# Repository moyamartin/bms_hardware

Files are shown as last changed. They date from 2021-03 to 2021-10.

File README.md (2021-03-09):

# Battery Management System (BMS) - Hardware

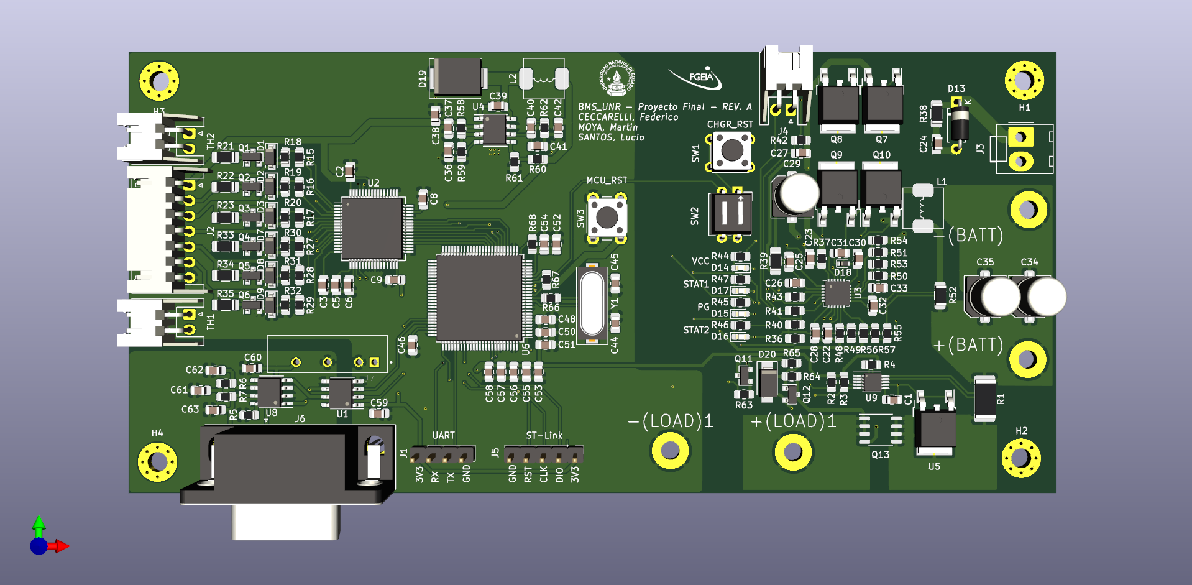
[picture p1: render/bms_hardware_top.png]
3d Render of the BMS


This is the hardware design section of the [BMS project](https://github.com/moyamartin/bms_unr). It was designed with [KiCAD](https://kicad.org/).

Here you will find the design, [gerber](./gerber/), [BOM](https://moyamartin.github.io/bms_hardware/) and [render](./render/) files of the PCB.

## Features

As the main goal of this project, this board is designed to support a li-ion
battery pack with a 6 series - 3 parallel architecture based on 18650PF cells
following the next goals:

* Protection
* Balancing
* Charging/Discharging
* Temperature measurement
* Battery SoC (State of Charge) estimation

## Design components/considerations

To meet the project's requirements we have chosen the following components with
their respective role:

* [BQ76PL536A](https://www.ti.com/product/BQ76PL536A): This is a 3 to 6 series
  lithium-ion battery monitor and secondary protection. It is used as a frontend
  analog device to measure each series cell voltage and it has dedicated outputs
  to balance passively through resistors the desired cell.

* [INA226](https://www.ti.com/lit/ds/symlink/ina226.pdf): Bi-Directional current
  and power monitor with I2C compatible interface, we are using this to measure
  the discharge current, fusioning this data with the voltage measurement of
  each cell we can infere the SoC of each cell.

* [BQ24618](https://www.ti.com/lit/ds/symlink/bq24618.pdf): 6 cells Li-Ion
  battery charger, designed to charge the battery pack at a 4A rate with led
  status indication.

* [STM32F407VGTx](https://www.st.com/en/microcontrollers-microprocessors/stm32f407vg.html): ARM Cortex-M microcontroller with DSP instructions and FPU unit, used to estimate the SoC and control all the peripherals and sensors through their respectives communication protocols applying all the mentioned features earlier. It is enabled to interact with other external devices (such as an on-board computer) through CAN and RS232.

* [SN65HVD233](https://www.ti.com/lit/ds/symlink/sn65hvd233.pdf): 3.3V CAN Bus
  transceiver to operate with the latter MCU compatible with ISO 11898 standard.
  This device is isolated from the rest of the components through the [ADuM1201AR](https://www.analog.com/media/en/technical-documentation/data-sheets/ADuM1200_1201.pdf).

* [IRF9310PbF](https://www.infineon.com/dgdl/irf9310pbf.pdf?fileId=5546d462533600a4015356110a7d1d95): Charge and Discarge switch for battery applications, this device is in charge of connection and disconnecting the load from the battery, basically, it's the main endpoint of proetection for the battery pack

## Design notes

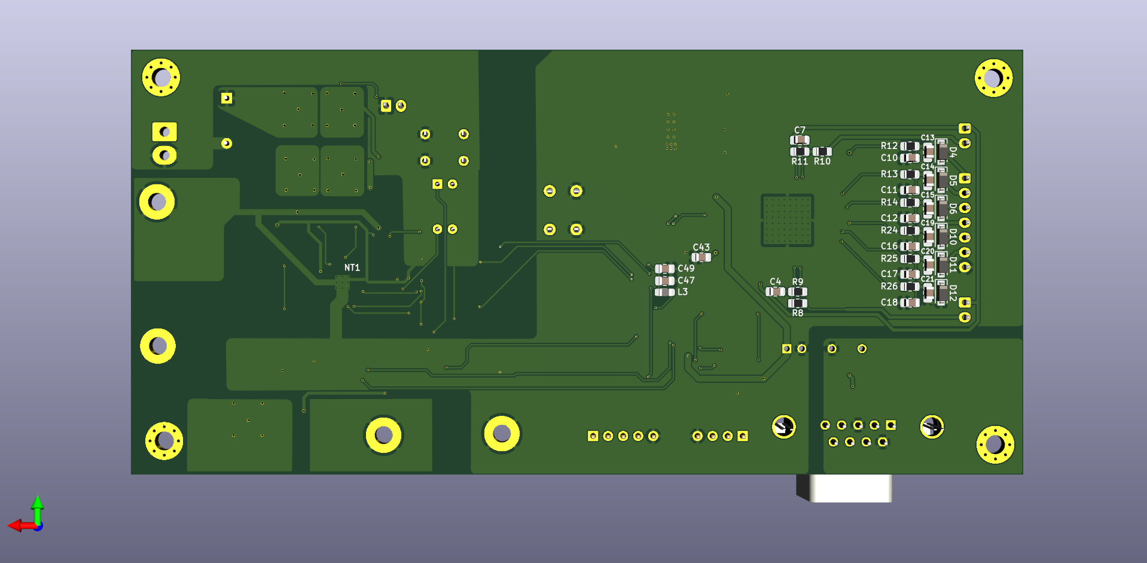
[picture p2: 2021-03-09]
render/bms_hardware_bottom.png

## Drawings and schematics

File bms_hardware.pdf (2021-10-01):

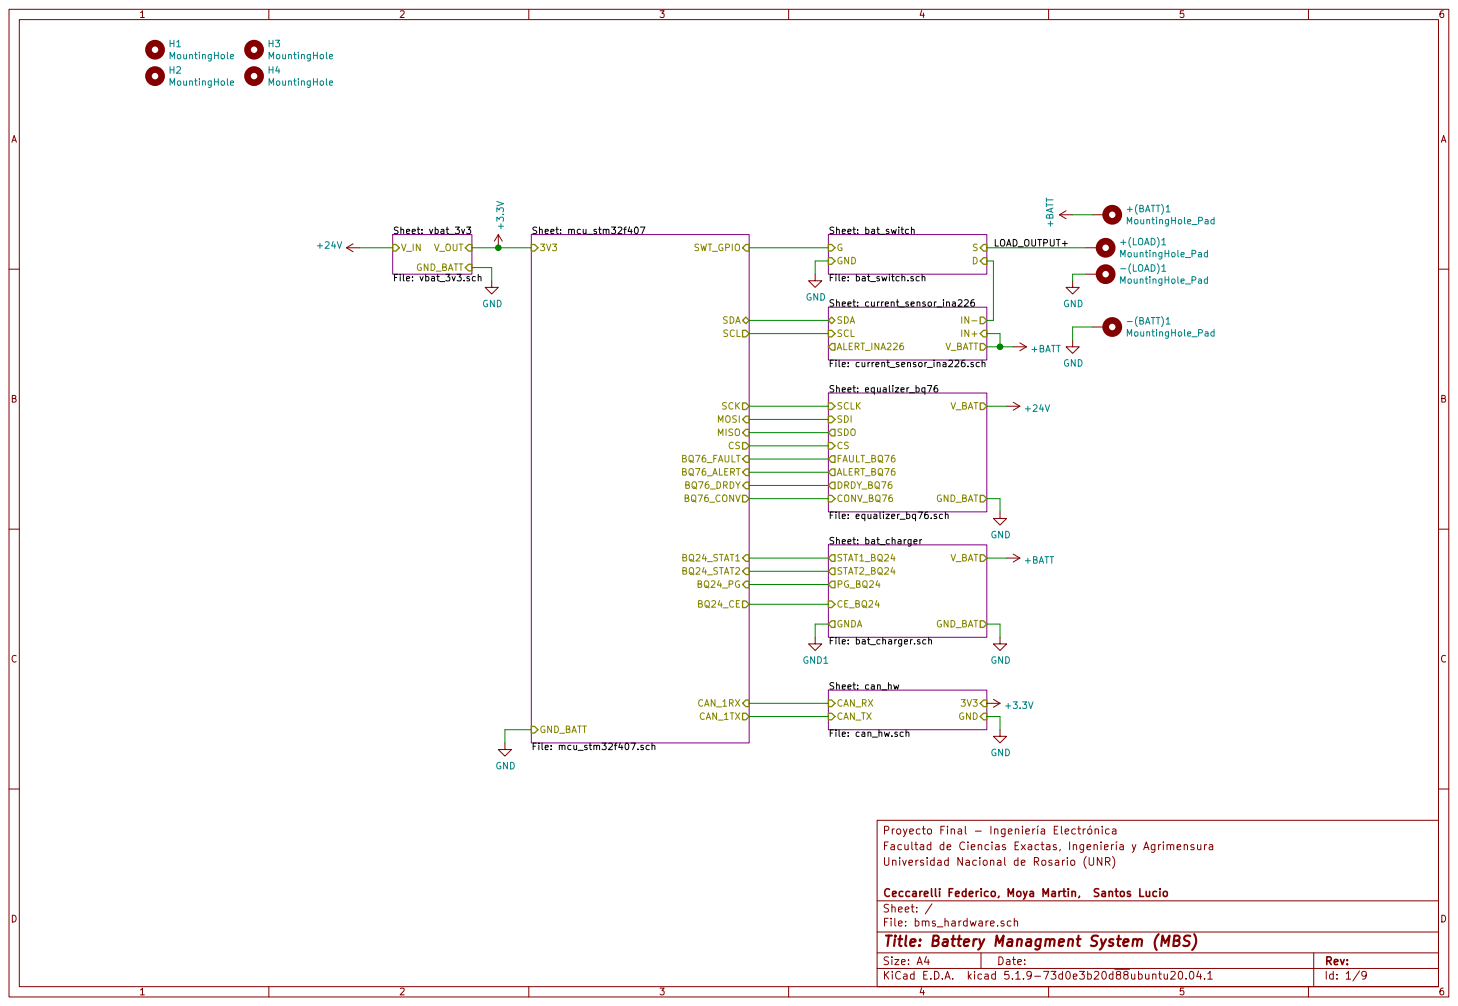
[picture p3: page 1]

Sheet: current_sensor_ina226 File: current_sensor_ina226.sch SDA

SDA
SCL SCK MISO MOSI CS

Proyecto Final - Ingeniería Electrónica
Facultad de Ciencias Exactas, Ingeniería y Agrimensura
Universidad Nacional de Rosario (UNR)

File: bms_hardware.sch Sheet: / Ceccarelli Federico, Moya Martin, Santos Lucio

Id: 1/9 Title: Battery Managment System (MBS)

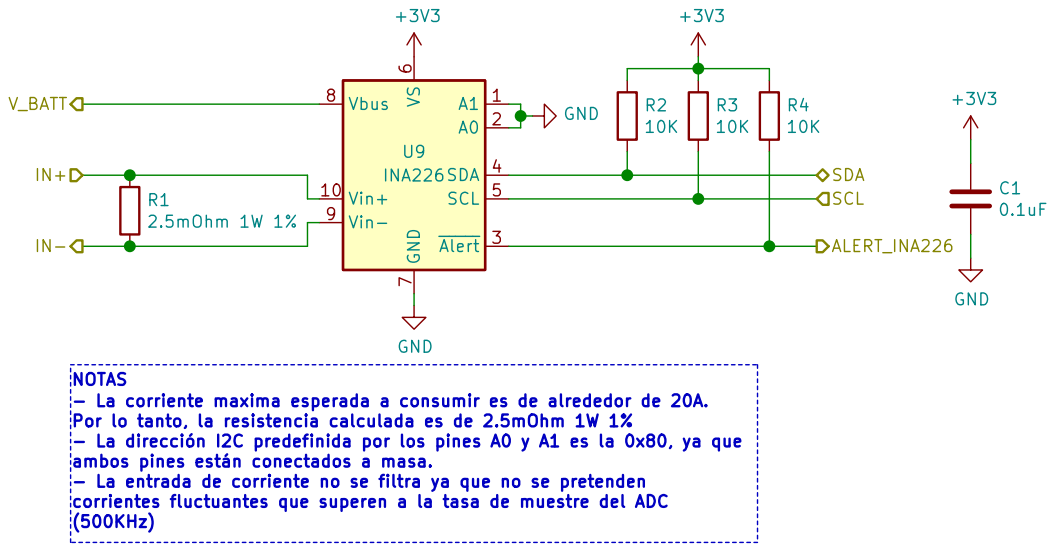
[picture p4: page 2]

- La corriente maxima esperada a consumir es de alrededor de 20A. Por lo tanto, la resistencia calculada es de 2.5mOhm 1W 1%

- La dirección I2C predefinida por los pines A0 y A1 es la 0x80, ya que
ambos pines están conectados a masa.
- La entrada de corriente no se filtra ya que no se pretenden
corrientes fluctuantes que superen a la tasa de muestre del ADC
(500KHz)

Proyecto Final - Ingeniería Electrónica
Facultad de Ciencias Exactas, Ingeniería y Agrimensura
Universidad Nacional de Rosario (UNR)

Ceccarelli Federico, Moya Martin, Santos Lucio
Sheet: /current_sensor_ina226/
File: current_sensor_ina226.sch
Id: 2/9 Title: Battery Managment System (MBS)

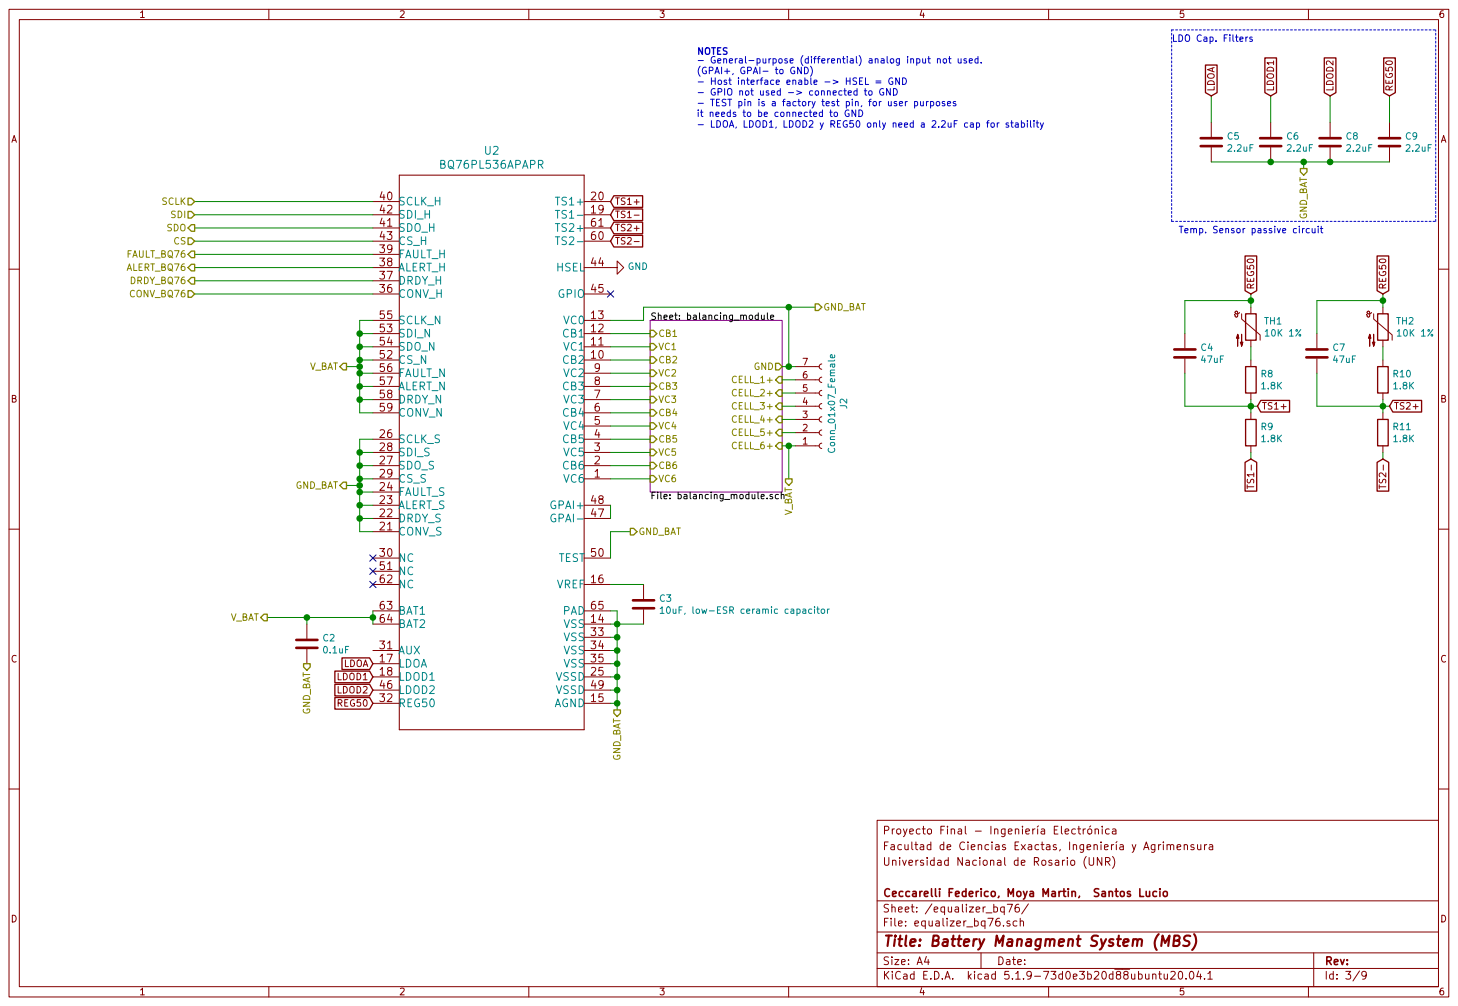
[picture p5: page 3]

LDO Cap. Filters NOTES

- General-purpose (differential) analog input not used.
(GPAI+, GPAI- to GND)
- Host interface enable -> HSEL = GND
- GPIO not used -> connected to GND
- TEST pin is a factory test pin, for user purposes
it needs to be connected to GND
- LDOA, LDOD1, LDOD2 y REG50 only need a 2.2uF cap for stability

Temp. Sensor passive circuit

10uF, low-ESR ceramic capacitor GND

Proyecto Final - Ingeniería Electrónica
Facultad de Ciencias Exactas, Ingeniería y Agrimensura
Universidad Nacional de Rosario (UNR)

Ceccarelli Federico, Moya Martin, Santos Lucio
Sheet: /equalizer_bq76/
File: equalizer_bq76.sch
Id: 3/9 Title: Battery Managment System (MBS)

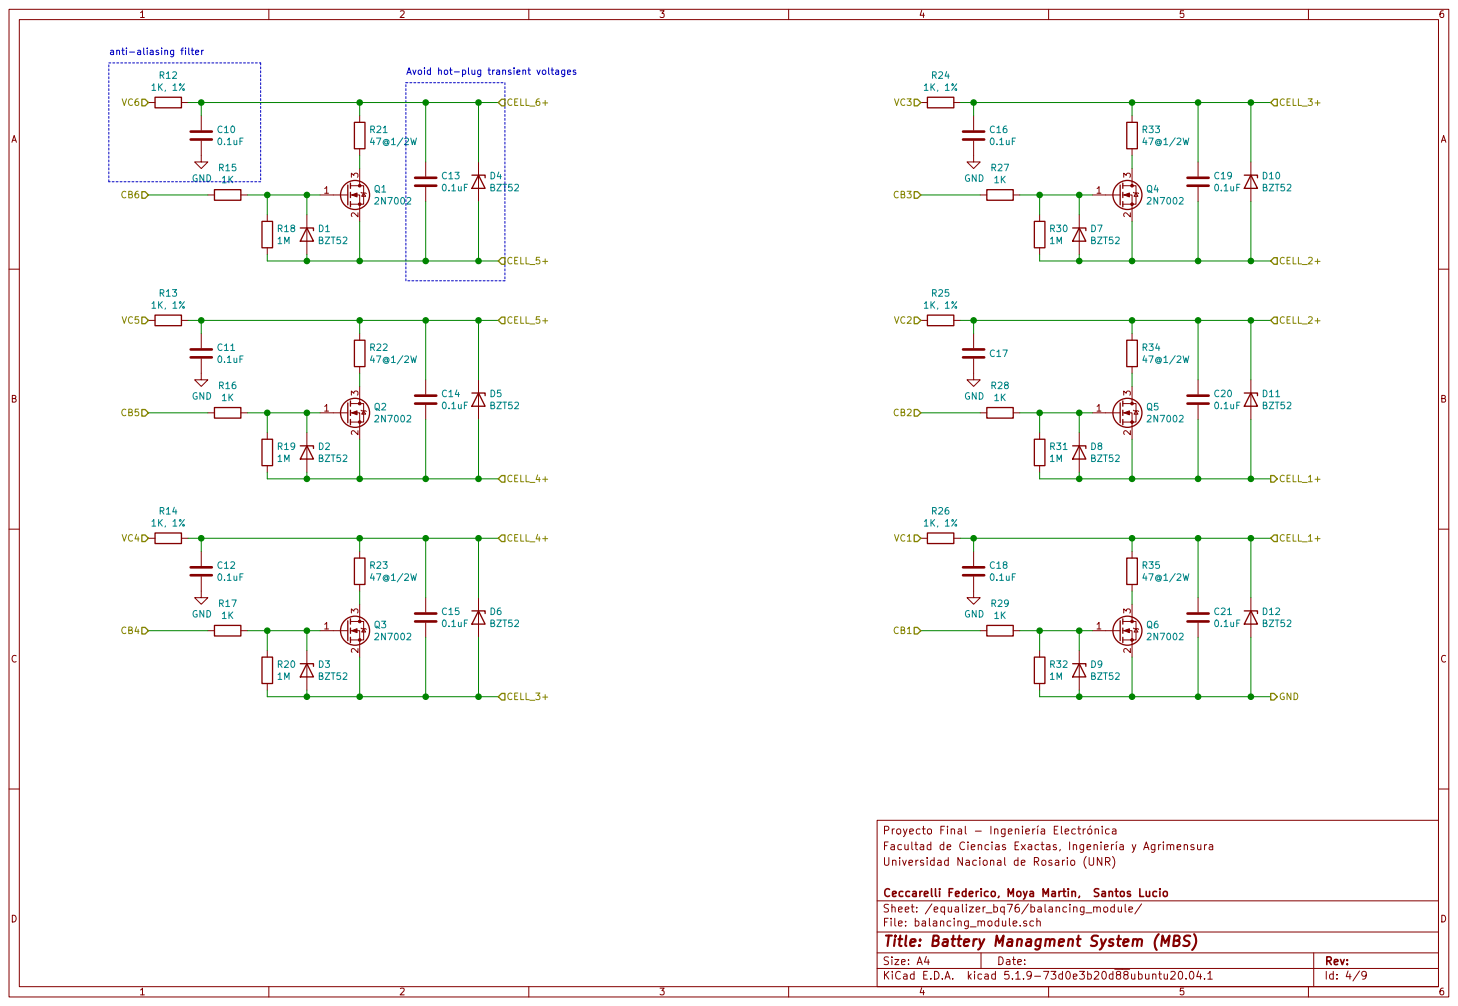
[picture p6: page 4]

Proyecto Final - Ingeniería Electrónica
Facultad de Ciencias Exactas, Ingeniería y Agrimensura
Universidad Nacional de Rosario (UNR)

Ceccarelli Federico, Moya Martin, Santos Lucio
Sheet: /equalizer_bq76/balancing_module/
File: balancing_module.sch
Id: 4/9 Title: Battery Managment System (MBS)

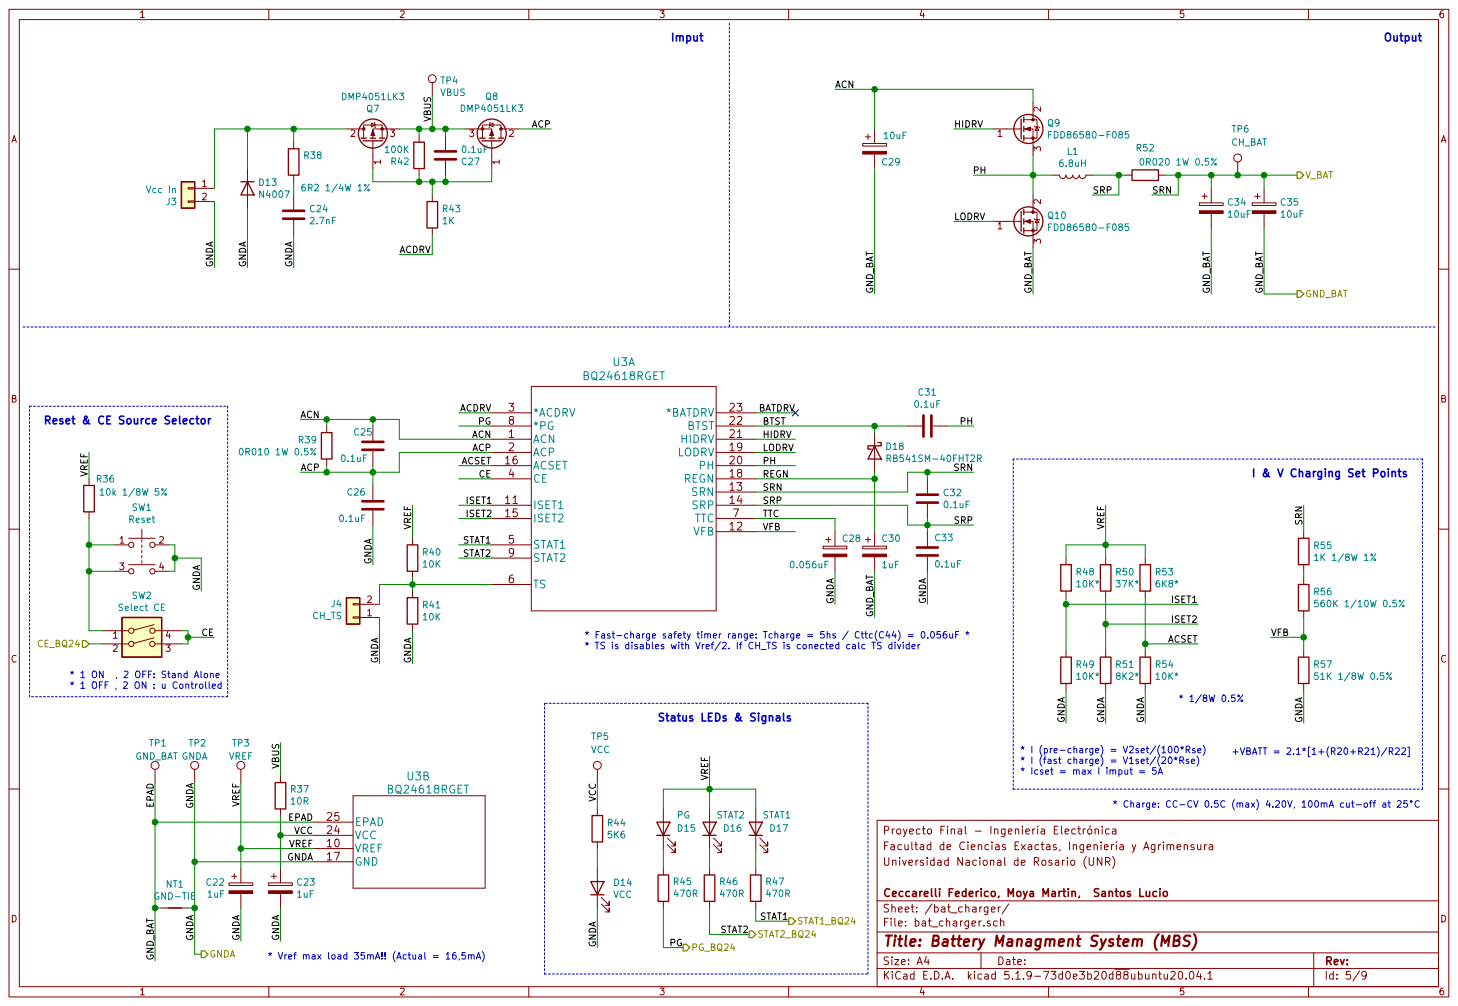
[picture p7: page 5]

* Fast-charge safety timer range: Tcharge = 5hs / Cttc(C44) = 0.056uF *

* Icset = max I imput = 5A * 1 ON , 2 OFF: Stand Alone
* 1 OFF , 2 ON : u Controlled

* Charge: CC-CV 0.5C (max) 4.20V, 100mA cut-off at 25°C

Proyecto Final - Ingeniería Electrónica
Facultad de Ciencias Exactas, Ingeniería y Agrimensura
Universidad Nacional de Rosario (UNR)

Ceccarelli Federico, Moya Martin, Santos Lucio
Sheet: /bat_charger/
File: bat_charger.sch
Id: 5/9 Title: Battery Managment System (MBS)

* Vref max load 35mA!! (Actual = 16,5mA)

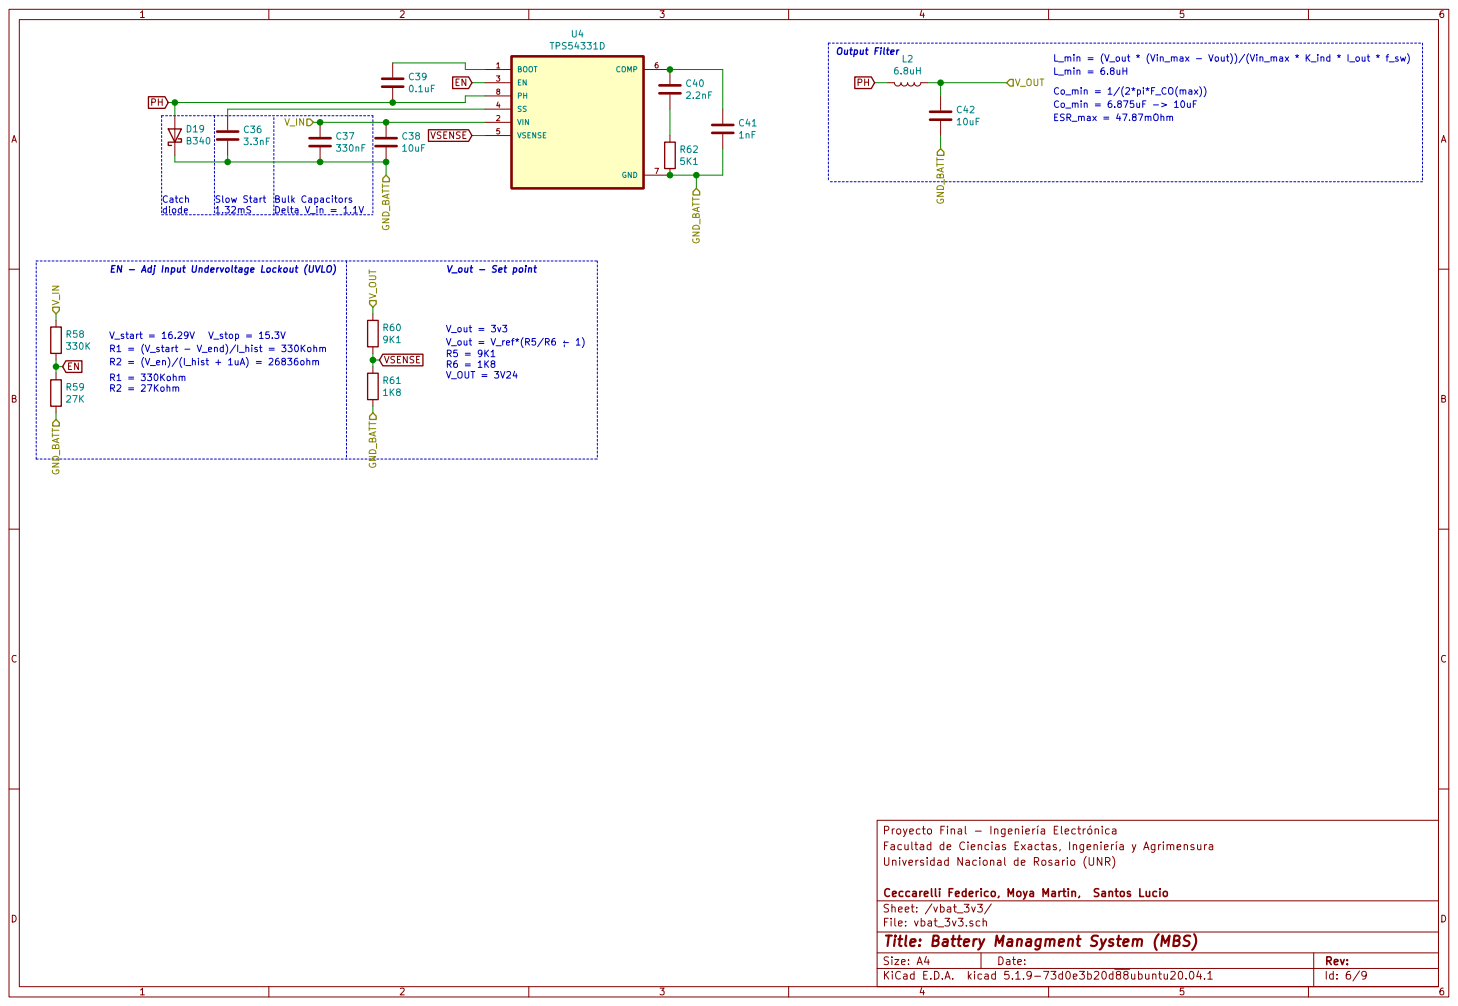
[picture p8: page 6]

Catch diode

Slow Start 1.32mS

EN - Adj Input Undervoltage Lockout (UVLO)

Proyecto Final - Ingeniería Electrónica
Facultad de Ciencias Exactas, Ingeniería y Agrimensura
Universidad Nacional de Rosario (UNR)

Ceccarelli Federico, Moya Martin, Santos Lucio
Sheet: /vbat_3v3/
File: vbat_3v3.sch
Id: 6/9 Title: Battery Managment System (MBS)

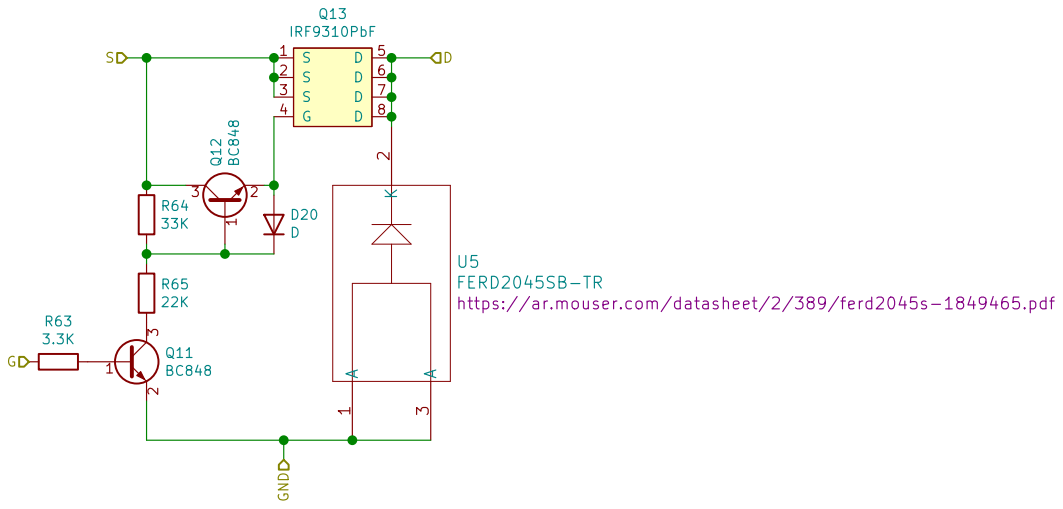
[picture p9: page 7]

https://ar.mouser.com/datasheet/2/389/ferd2045s-1849465.pdf GND

Proyecto Final - Ingeniería Electrónica
Facultad de Ciencias Exactas, Ingeniería y Agrimensura
Universidad Nacional de Rosario (UNR)

Ceccarelli Federico, Moya Martin, Santos Lucio
Sheet: /bat_switch/
File: bat_switch.sch
Id: 7/9 Title: Battery Managment System (MBS)

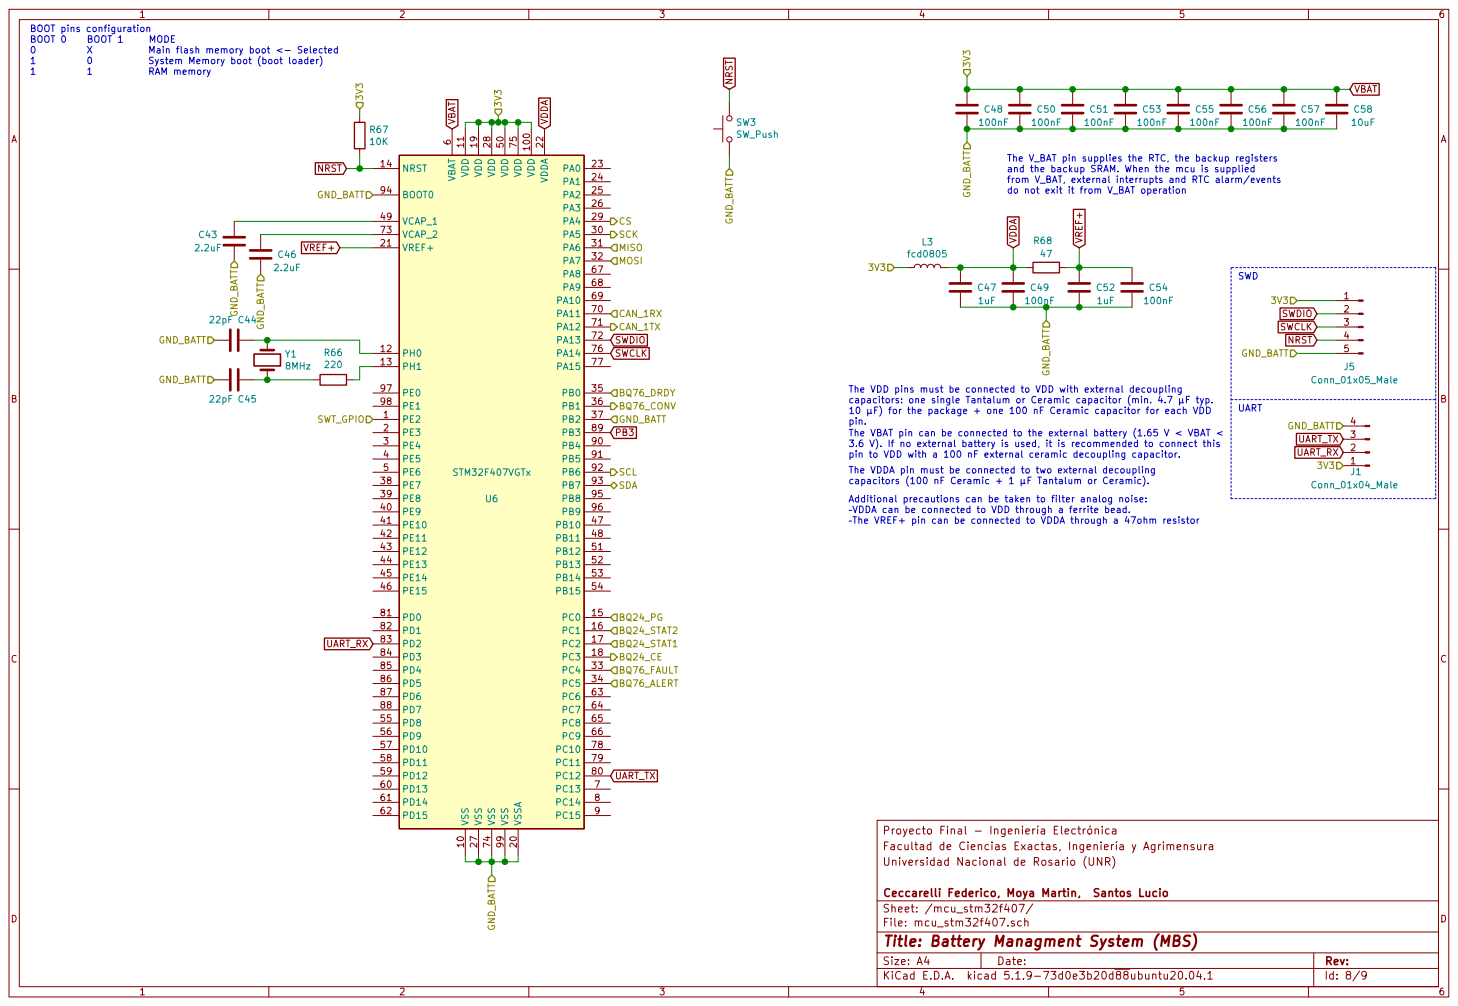
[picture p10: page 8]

PB3 VREF+ BOOT pins configuration BOOT 0 BOOT 1 MODE

SWCLK NRST VREF+ NRST SWCLK

6 VCAP_1 49 VCAP_2 73 VDD 100 VDD 11 VDD 19 VDD 28 VDD 50 VDD 75 VDDA 22 VREF+ 21 VSS 10 VSS 27 VSS 74 VSS 99 VSSA 20 U6 STM32F407VGTx C54

The V_BAT pin supplies the RTC, the backup registers
and the backup SRAM. When the mcu is supplied
from V_BAT, external interrupts and RTC alarm/events
do not exit it from V_BAT operation

The VDD pins must be connected to VDD with external decoupling
capacitors: one single Tantalum or Ceramic capacitor (min. 4.7 F typ.
10 F) for the package + one 100 nF Ceramic capacitor for each VDD
pin.
The VBAT pin can be connected to the external battery (1.65 V < VBAT <
3.6 V). If no external battery is used, it is recommended to connect this
pin to VDD with a 100 nF external ceramic decoupling capacitor.
The VDDA pin must be connected to two external decoupling

Additional precautions can be taken to filter analog noise:
VDDA can be connected to VDD through a ferrite bead.
The VREF+ pin can be connected to VDDA through a 47ohm resistor
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

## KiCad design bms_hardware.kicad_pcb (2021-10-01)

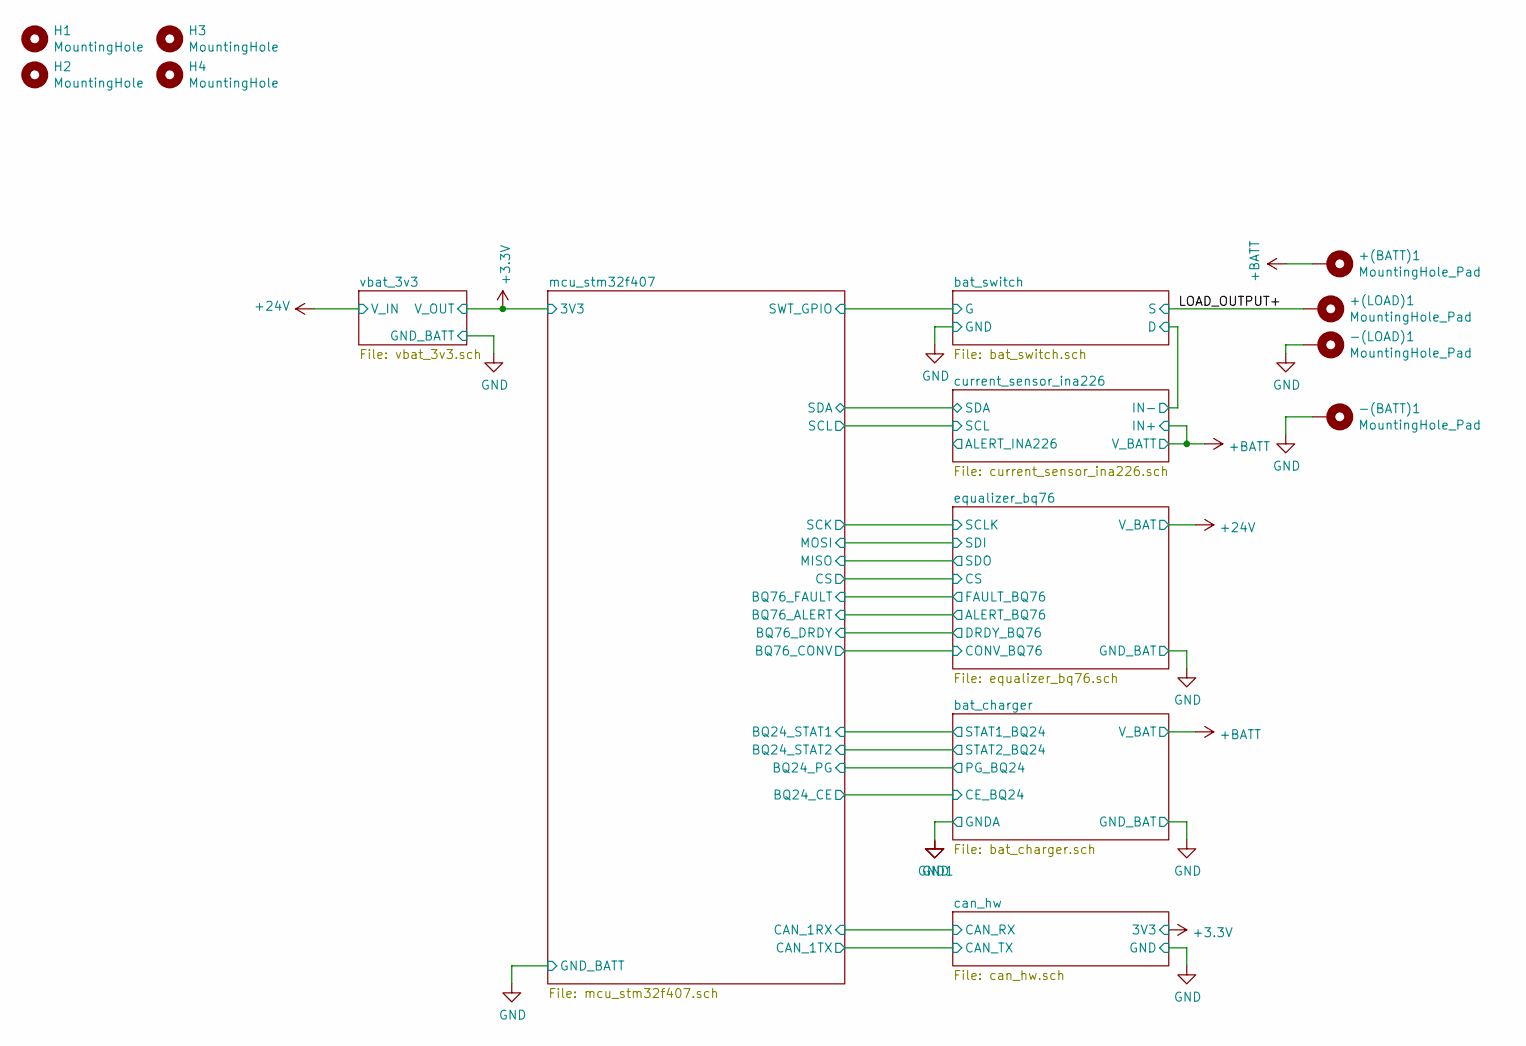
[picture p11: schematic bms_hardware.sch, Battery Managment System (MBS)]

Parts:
+(BATT)1: MountingHole_Pad; MountingHole_3mm_Pad_TopBottom
+(LOAD)1: MountingHole_Pad; MountingHole_3mm_Pad_TopBottom
-(BATT)1: MountingHole_Pad; MountingHole_3mm_Pad_TopBottom
-(LOAD)1: MountingHole_Pad; MountingHole_3mm_Pad_TopBottom
H1, H2, H3, H4: MountingHole; MountingHole_3.2mm_M3_Pad_Via

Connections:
/LOAD_OUTPUT+: +(LOAD)1.1; also elsewhere on the board

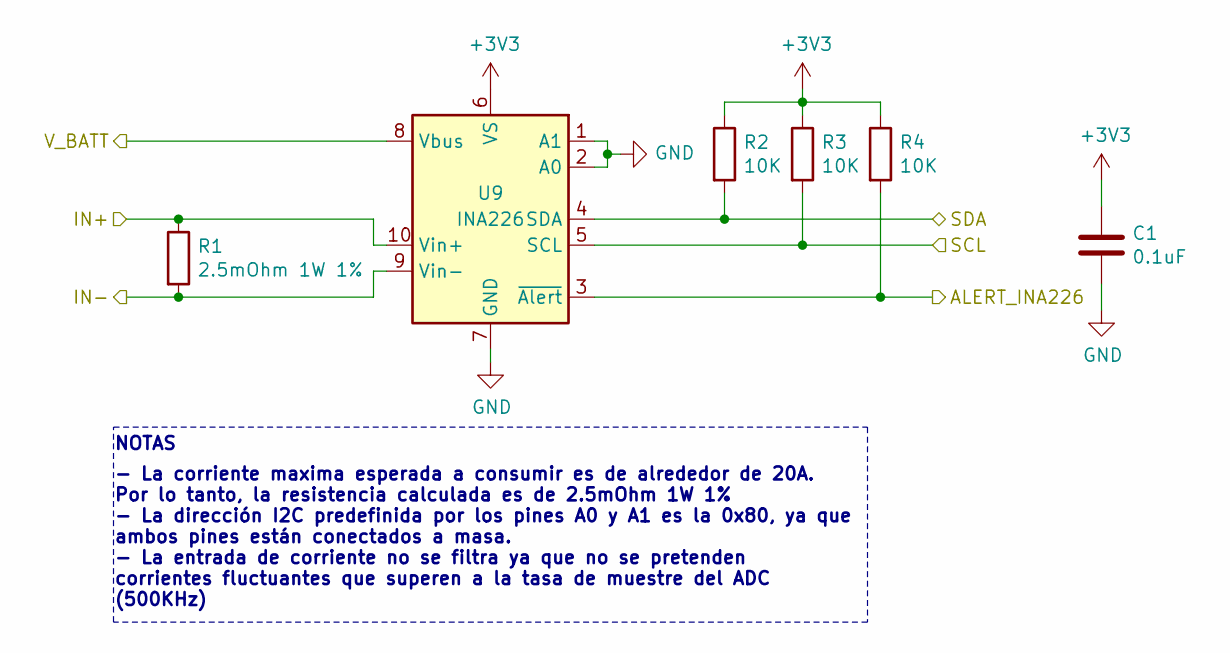
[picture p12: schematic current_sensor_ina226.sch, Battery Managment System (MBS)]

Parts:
C1: 0.1uF; C_0805_2012Metric_Pad1.18x1.45mm_HandSolder
R1: 2.5mOhm 1W 1%; R_2512_6332Metric_Pad1.40x3.35mm_HandSolder
R2, R3, R4: 10K; R_0805_2012Metric_Pad1.20x1.40mm_HandSolder
U9: INA226; VSSOP-10_3x3mm_P0.5mm

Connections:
+BATT: R1.1, U9.8 (Vbus), U9.10 (Vin+); also elsewhere on the board
/current_sensor_ina226/ALERT_INA226: R4.2, U9.3 (~Alert~)
/current_sensor_ina226/SCL: R3.2, U9.5 (SCL); also elsewhere on the board
/current_sensor_ina226/SDA: R2.2, U9.4 (SDA); also elsewhere on the board
VBAT: C1.1, R2.1, R3.1, R4.1, U9.6 (VS); also elsewhere on the board

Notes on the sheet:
NOTAS
- La corriente maxima esperada a consumir es de alrededor de 20A. Por lo tanto, la resistencia calculada es de 2.5mOhm 1W 1% - La dirección I2C predefinida por los pines A0 y A1 es la 0x80, ya que ambos pines están conectados a masa. - La entrada de corriente no se filtra ya que no se pretenden cor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

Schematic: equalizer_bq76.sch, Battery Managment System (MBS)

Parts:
C2: 0.1uF; C_0805_2012Metric_Pad1.18x1.45mm_HandSolder
C3: 10uF, low-ESR ceramic capacitor; C_0805_2012Metric_Pad1.18x1.45mm_HandSolder
C4, C7: 47uF; C_0805_2012Metric_Pad1.18x1.45mm_HandSolder
C5, C6, C8, C9: 2.2uF; C_0805_2012Metric_Pad1.18x1.45mm_HandSolder
J2: Conn_01x07_Female; JST_XH_S7B-XH-A_1x07_P2.50mm_Horizontal
R8, R9, R10, R11: 1.8K; R_0805_2012Metric_Pad1.20x1.40mm_HandSolder
TH1, TH2: 10K 1%; JST_XH_S2B-XH-A_1x02_P2.50mm_Horizontal
U2: BQ76PL536APAPR; HTQFP-64-1EP_10x10mm_P0.5mm_EP8x8mm_Mask4.4x4.4mm_ThermalVi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

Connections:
+24V: C2.1, J2.1, U2.52, U2.53, U2.54, U2.55, U2.56, U2.57, U2.58, U2.59, U2.63, U2.64; also elsewhere on the board
/equalizer_bq76/ALERT_BQ76: U2.38; also elsewhere on the board
/equalizer_bq76/CS: U2.43; also elsewhere on the board
/equalizer_bq76/balancing_module/CB1: U2.12; also elsewhere on the board
/equalizer_bq76/balancing_module/CB2: U2.10; also elsewhere on the board
/equalizer_bq76/balancing_module/CB3: U2.8; also elsewhere on the board
/equalizer_bq76/balancing_module/CB4: U2.6; also elsewhere on the board
/equalizer_bq76/balancing_module/CB5: U2.4; also elsewhere on the board
/equalizer_bq76/balancing_module/CB6: U2.2; also elsewhere on the board
/equalizer_bq76/balancing_module/CELL_1+: J2.6; also elsewhere on the board
/equalizer_bq76/balancing_module/CELL_2+: J2.5; also elsewhere on the board
/equalizer_bq76/balancing_module/CELL_3+: J2.4; also elsewhere on the board
/equalizer_bq76/balancing_module/CELL_4+: J2.3; also elsewhere on the board
/equalizer_bq76/balancing_module/CELL_5+: J2.2; also elsewhere on the board
/equalizer_bq76/balancing_module/VC1: U2.11; also elsewhere on the board
/equalizer_bq76/balancing_module/VC2: U2.9; also elsewhere on the board
/equalizer_bq76/balancing_module/VC3: U2.7; also elsewhere on the board
/equalizer_bq76/balancing_module/VC4: U2.5; also elsewhere on the board
/equalizer_bq76/balancing_module/VC5: U2.3; also elsewhere on the board
/equalizer_bq76/balancing_module/VC6: U2.1; also elsewhere on the board
/mcu_stm32f407/BQ76_CONV: U2.36; also elsewhere on the board
/mcu_stm32f407/BQ76_DRDY: U2.37; also elsewhere on the board
/mcu_stm32f407/BQ76_FAULT: U2.39; also elsewhere on the board
/mcu_stm32f407/MISO: U2.41; also elsewhere on the board
/mcu_stm32f407/MOSI: U2.42; also elsewhere on the board
/mcu_stm32f407/SCK: U2.40; also elsewhere on the board
LDOA: C5.1, U2.17
LDOD1: C6.1, U2.18
LDOD2: C8.1, U2.46
unnamed: C3.1, U2.16
unnamed: R8.1, TH1.2
unnamed: R10.1, TH2.2
unnamed: U2.47, U2.48
REG50: C4.1, C7.1, C9.1, TH1.1, TH2.1, U2.32
TS1+: C4.2, R8.2, R9.1, U2.20
TS1-: R9.2, U2.19
TS2+: C7.2, R10.2, R11.1, U2.61
TS2-: R11.2, U2.60

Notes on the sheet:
LDO Cap. Filters
NOTES
- General-purpose (differential) analog input not used. (GPAI+, GPAI- to GND) - Host interface enable -> HSEL = GND - GPIO not used -> connected to GND - TEST pin is a factory test pin, for user purposes it needs to be connected to GND - LDOA, LDOD1, LDOD2 y REG50 only need a 2.2uF cap for stability
Temp. Sensor passive circuit

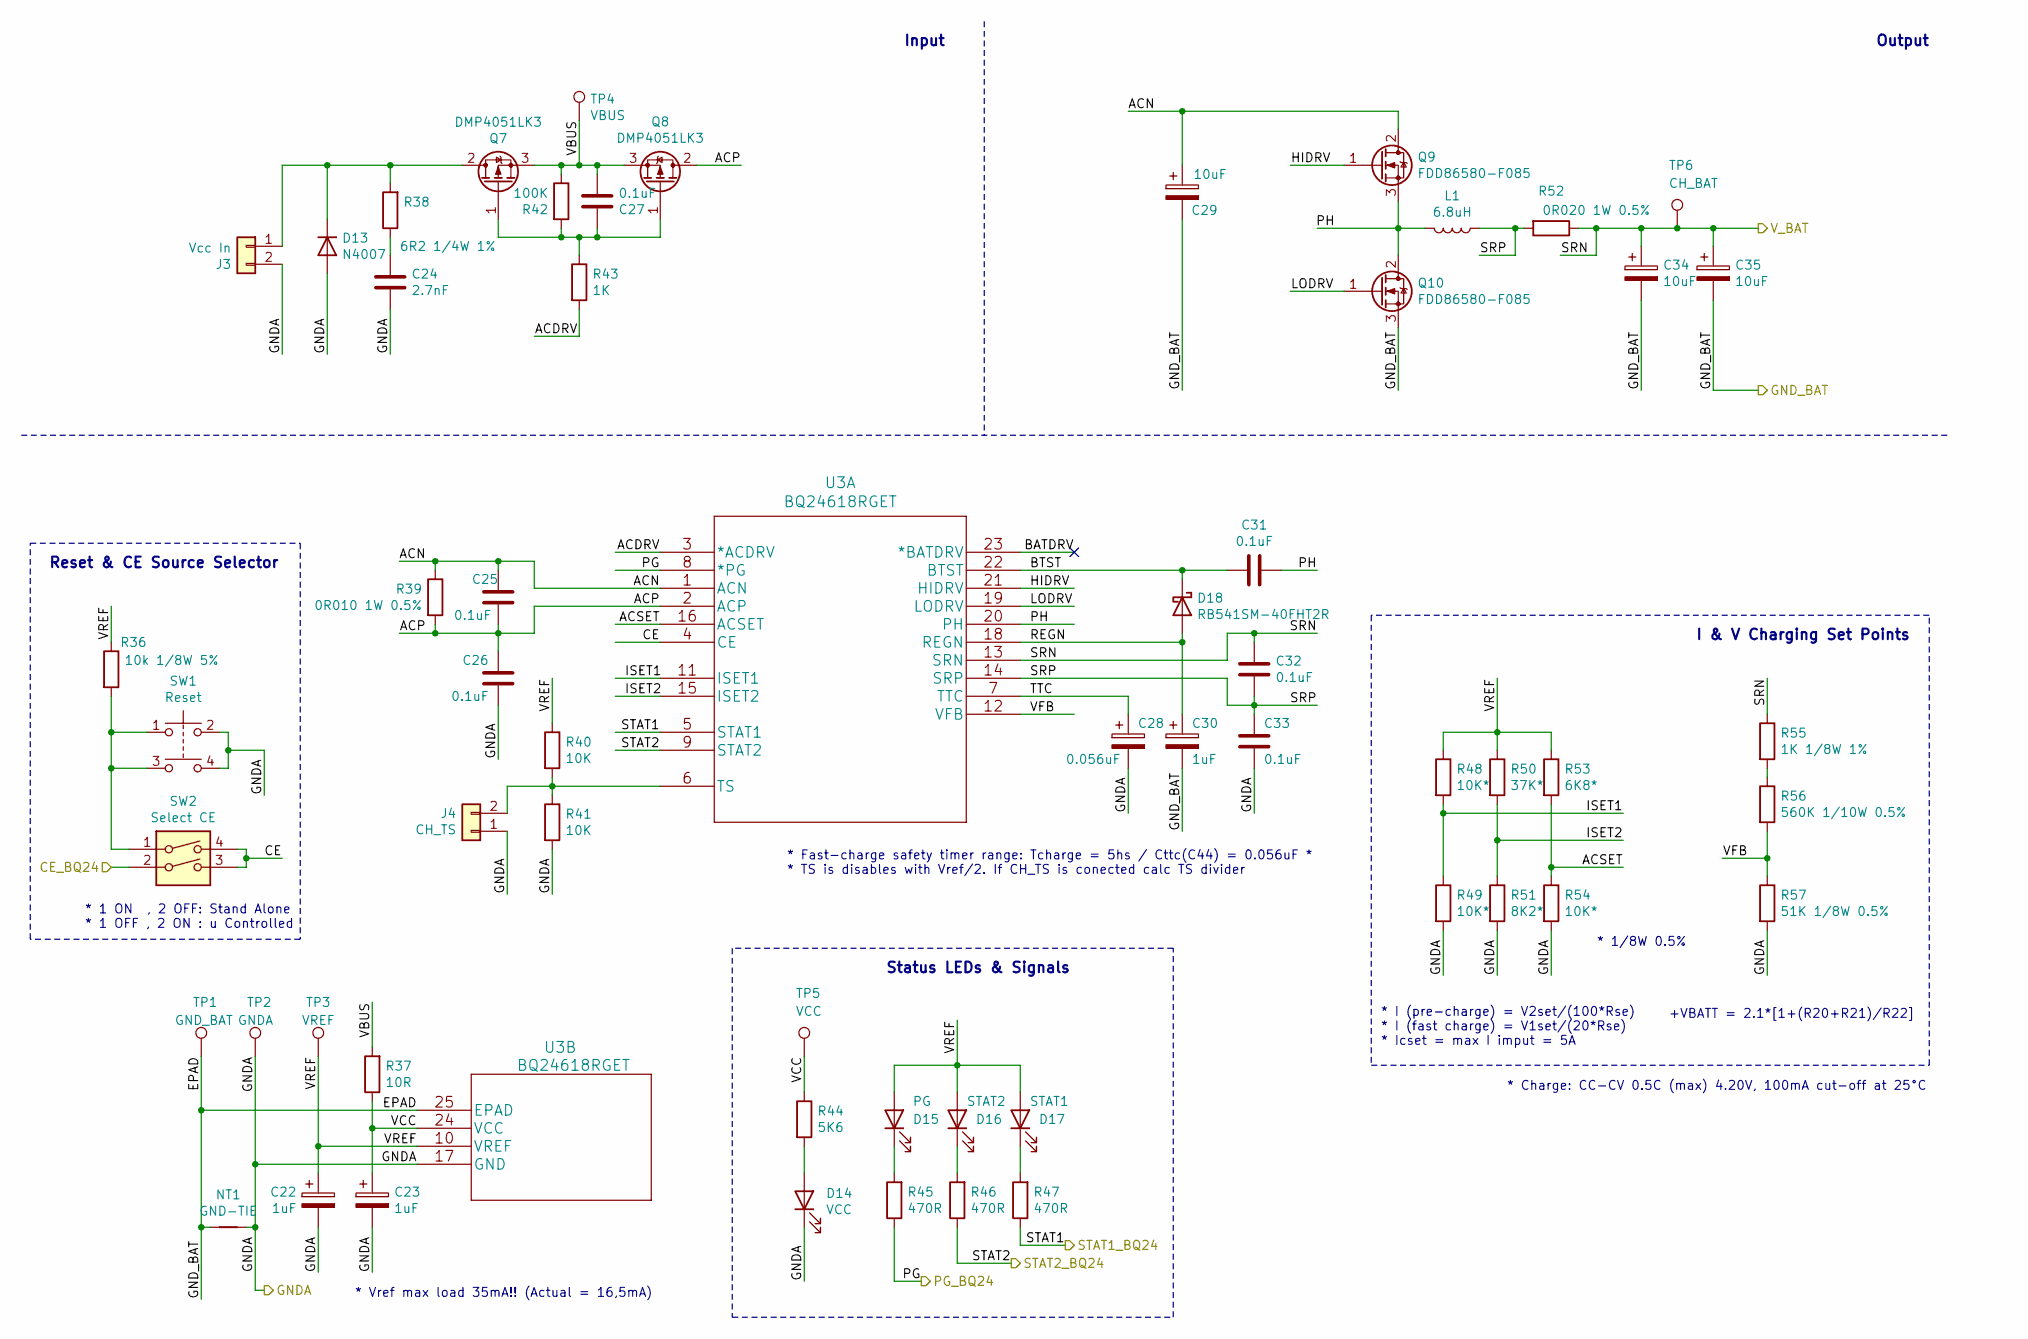
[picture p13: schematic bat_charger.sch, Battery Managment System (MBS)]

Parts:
C22, C23, C30: 1uF; C_0805_2012Metric_Pad1.18x1.45mm_HandSolder
C24: 2.7nF; C_0805_2012Metric_Pad1.18x1.45mm_HandSolder
C25, C26, C27, C31, C32, C33: 0.1uF; C_0805_2012Metric_Pad1.18x1.45mm_HandSolder
C28: 0.056uF; C_0805_2012Metric_Pad1.18x1.45mm_HandSolder
C29, C34, C35: 10uF; C_Elec_6.3x7.7
D13: N4007; D_A-405_P7.62mm_Horizontal
D14: VCC; LED_0603_1608Metric_Pad1.05x0.95mm_HandSolder
D15: PG; LED_0603_1608Metric_Pad1.05x0.95mm_HandSolder
D16: STAT2; LED_0603_1608Metric_Pad1.05x0.95mm_HandSolder
D17: STAT1; LED_0603_1608Metric_Pad1.05x0.95mm_HandSolder
D18: RB541SM-40FHT2R; D_SOD-523
J3: Vcc In; Molex_KK-396_A-41791-0002_1x02_P3.96mm_Vertical
J4: CH_TS; JST_XH_S2B-XH-A_1x02_P2.50mm_Horizontal
L1: 6.8uH; L_BOURNS_SRP6030
NT1: GND-TIE; NetTie-2_SMD_Pad2.0mm
Q7, Q8: DMP4051LK3; TO-252-2
Q9, Q10: FDD86580-F085; TO-252-2
R36: 10k 1/8W 5%; R_0805_2012Metric_Pad1.20x1.40mm_HandSolder
R37: 10R; R_0805_2012Metric_Pad1.20x1.40mm_HandSolder
R38: 6R2 1/4W 1%; R_1206_3216Metric_Pad1.30x1.75mm_HandSolder
R39: 0R010⁯ 1W 0.5%; R_1206_3216Metric_Pad1.30x1.75mm_HandSolder
R40, R41: 10K; R_0805_2012Metric_Pad1.20x1.40mm_HandSolder
R42: 100K; R_0805_2012Metric_Pad1.20x1.40mm_HandSolder
R43: 1K; R_0805_2012Metric_Pad1.20x1.40mm_HandSolder
R44: 5K6; R_0805_2012Metric_Pad1.20x1.40mm_HandSolder
R45, R46, R47: 470R; R_0805_2012Metric_Pad1.20x1.40mm_HandSolder
R48, R49, R54: 10K*; R_0805_2012Metric_Pad1.20x1.40mm_HandSolder
R50: 37K*; R_0805_2012Metric_Pad1.20x1.40mm_HandSolder
R51: 8K2*; R_0805_2012Metric_Pad1.20x1.40mm_HandSolder
R52: 0R020 1W 0.5%; R_1206_3216Metric_Pad1.30x1.75mm_HandSolder
R53: 6K8*; R_0805_2012Metric_Pad1.20x1.40mm_HandSolder
R55: 1K 1/8W 1%; R_0805_2012Metric_Pad1.20x1.40mm_HandSolder
R56: 560K 1/10W 0.5%; R_0805_2012Metric_Pad1.20x1.40mm_HandSolder
R57: 51K 1/8W 0.5%; R_0805_2012Metric_Pad1.20x1.40mm_HandSolder
SW1: Reset; SW_TH_Tactile_Omron_B3F-10xx
SW2: Select CE; SW_DIP_SPSTx02_Slide_6.7x6.64mm_W7.62mm_P2.54mm_LowProfile
TP1: GND_BAT; KEYSTONE_5016
TP2: GNDA; KEYSTONE_5016
TP3: VREF; KEYSTONE_5016
TP4: VBUS; KEYSTONE_5016
TP5: VCC; KEYSTONE_5016
TP6: CH_BAT; KEYSTONE_5016
U3: BQ24618RGET; VQFN-24-1EP_4x4mm_P0.5mm_EP2.45x2.45mm_ThermalVias

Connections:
+BATT: C32.1, C34.1, C35.1, R52.1, R55.1, TP6.1, U3.13 (SRN); also elsewhere on the board
/bat_charger/ACDRV: R43.2, U3.3 (*ACDRV)
/bat_charger/ACN: C25.2, C29.1, Q9.2 (D), R39.1, U3.1 (ACN)
/bat_charger/ACP: C25.1, C26.1, Q8.2 (D), R39.2, U3.2 (ACP)
/bat_charger/ACSET: R53.2, R54.1, U3.16 (ACSET)
/bat_charger/BATDRV: U3.23 (*BATDRV)
/bat_charger/BTST: C31.1, D18.1 (K), U3.22 (BTST)
/bat_charger/CE: SW2.3, SW2.4, U3.4 (CE)
/bat_charger/HIDRV: Q9.1 (G), U3.21 (HIDRV)
/bat_charger/ISET1: R48.2, R49.1, U3.11 (ISET1)
/bat_charger/ISET2: R50.2, R51.1, U3.15 (ISET2)
/bat_charger/LODRV: Q10.1 (G), U3.19 (LODRV)
/bat_charger/PH: C31.2, L1.2, Q9.3 (S), Q10.2 (D), U3.20 (PH)
/bat_charger/REGN: C30.1, D18.2 (A), U3.18 (REGN)
/bat_charger/SRP: C32.2, C33.2, L1.1, R52.2, U3.14 (SRP)
/bat_charger/TTC: C28.1, U3.7 (TTC)
/bat_charger/VBUS: C27.1, Q7.3 (S), Q8.3 (S), R37.2, R42.1, TP4.1
/bat_charger/VCC: C23.1, R37.1, R44.1, TP5.1, U3.24 (VCC)
/bat_charger/VFB: R56.2, R57.1, U3.12 (VFB)
/bat_charger/VREF: C22.1, D15.2 (A), D16.2 (A), D17.2 (A), R36.1, R40.1, R48.1, R50.1, R53.1, TP3.1, U3.10 (VREF)
/mcu_stm32f407/BQ24_CE: SW2.2; also elsewhere on the board
/mcu_stm32f407/BQ24_PG: R45.1, U3.8 (*PG); also elsewhere on the board
/mcu_stm32f407/BQ24_STAT1: R47.1, U3.5 (STAT1); also elsewhere on the board
/mcu_stm32f407/BQ24_STAT2: R46.1, U3.9 (STAT2); also elsewhere on the board
GND1: C22.2, C23.2, C24.2, C26.2, C28.2, C33.1, D13.2 (A), D14.1 (K), J3.2, J4.1, NT1.2, R41.2, R49.2, R51.2, R54.2, R57.2, SW1.2, SW1.4, TP2.1, U3.17 (GND)
unnamed: C24.1, R38.1
unnamed: C27.2, Q7.1 (G), Q8.1 (G), R42.2, R43.1
unnamed: D13.1 (K), J3.1, Q7.2 (D), R38.2
unnamed: D14.2 (A), R44.2
unnamed: D15.1 (K), R45.2
unnamed: D16.1 (K), R46.2
unnamed: D17.1 (K), R47.2
unnamed: J4.2, R40.2, R41.1, U3.6 (TS)
unnamed: R36.2, SW1.1, SW1.3, SW2.1
unnamed: R55.2, R56.1

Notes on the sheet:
Status LEDs & Signals
Reset & CE Source Selector
* 1 ON , 2 OFF: Stand Alone * 1 OFF , 2 ON : u Controlled
* 1/8W 0.5%
I & V Charging Set Points
* I (pre-charge) = V2set/(100*Rse) * I (fast charge) = V1set/(20*Rse) * Icset = max I imput = 5A
* Charge: CC-CV 0.5C (max) 4.20V, 100mA cut-off at 25°C
+VBATT = 2.1*[1+(R20+R21)/R22]
* Fast-charge safety timer range: Tcharge = 5hs / Cttc(C44) = 0.056uF * * TS is disables with Vref/2. If CH_TS is conected calc TS divider
* Vref max load 35mA!! (Actual = 16,5mA)
Input
Output

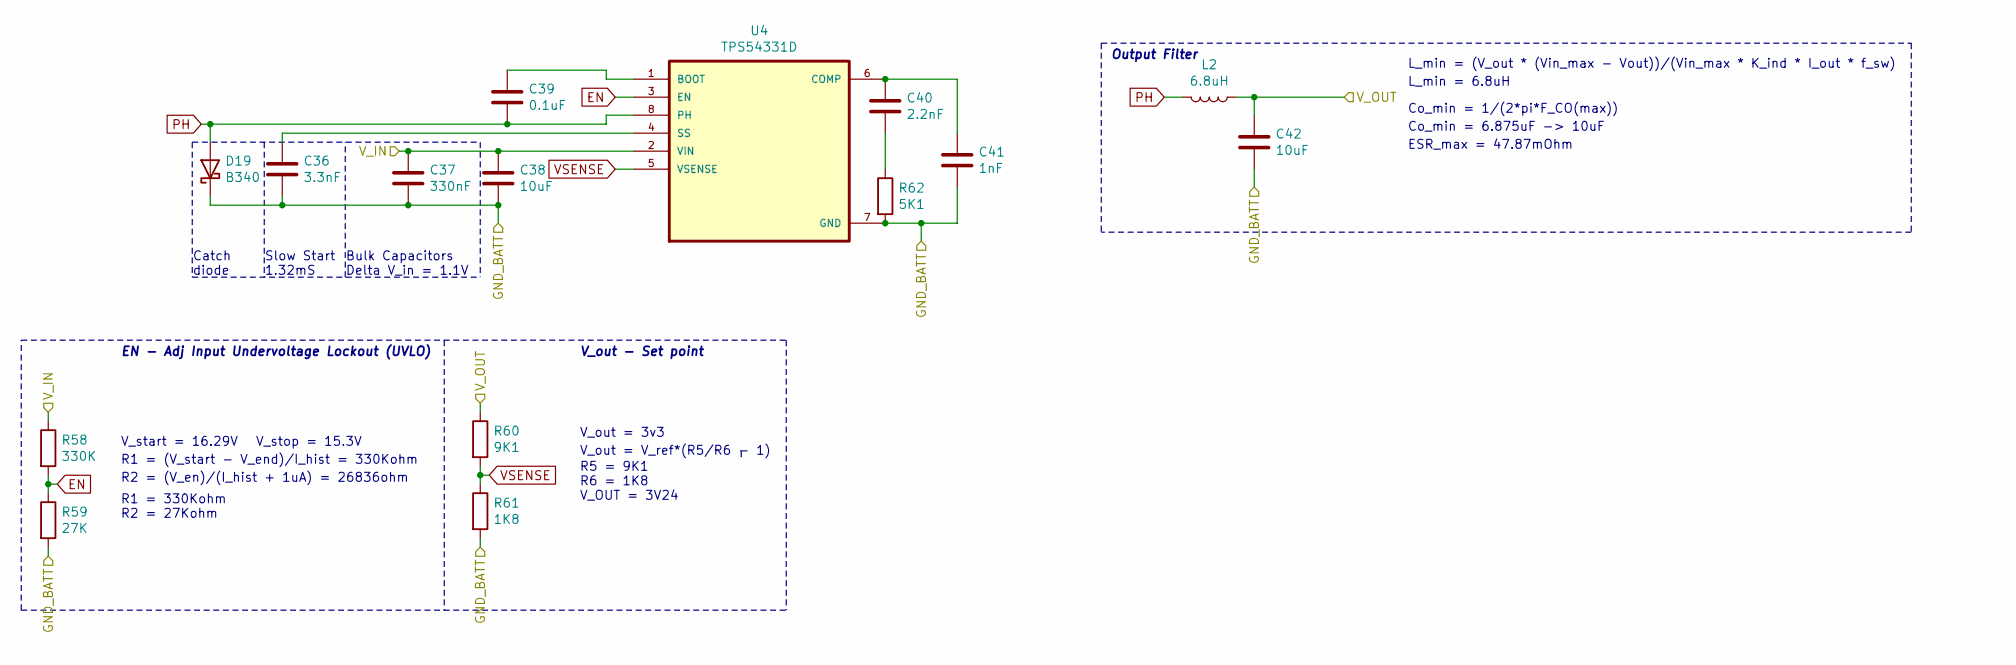
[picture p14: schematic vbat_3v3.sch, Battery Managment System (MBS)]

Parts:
C36: 3.3nF; C_0805_2012Metric_Pad1.18x1.45mm_HandSolder
C37: 330nF; C_0805_2012Metric_Pad1.18x1.45mm_HandSolder
C38, C42: 10uF; C_0805_2012Metric_Pad1.18x1.45mm_HandSolder
C39: 0.1uF; C_0805_2012Metric_Pad1.18x1.45mm_HandSolder
C40: 2.2nF; C_0805_2012Metric_Pad1.18x1.45mm_HandSolder
C41: 1nF; C_0805_2012Metric_Pad1.18x1.45mm_HandSolder
D19: B340; D_SMC
L2: 6.8uH; L_BOURNS_SRP6030
R58: 330K; R_0805_2012Metric_Pad1.20x1.40mm_HandSolder
R59: 27K; R_0805_2012Metric_Pad1.20x1.40mm_HandSolder
R60: 9K1; R_0805_2012Metric_Pad1.20x1.40mm_HandSolder
R61: 1K8; R_0805_2012Metric_Pad1.20x1.40mm_HandSolder
R62: 5K1; R_0805_2012Metric_Pad1.20x1.40mm_HandSolder
U4: TPS54331D; SOIC-8_3.9x4.9mm_P1.27mm

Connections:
+24V: C37.1, C38.1, R58.1, U4.2 (VIN); also elsewhere on the board
EN: R58.2, R59.1, U4.3 (EN)
unnamed: C36.1, U4.4 (SS)
unnamed: C39.1, U4.1 (BOOT)
unnamed: C40.1, C41.1, U4.6 (COMP)
unnamed: C40.2, R62.1
PH: C39.2, D19.2 (A), L2.2, U4.8 (PH)
VBAT: C42.1, L2.1, R60.1; also elsewhere on the board
VSENSE: R60.2, R61.1, U4.5 (VSENSE)

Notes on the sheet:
EN - Adj Input Undervoltage Lockout (UVLO)
V_start = 16.29V
V_stop = 15.3V
R1 = (V_start - V_end)/I_hist = 330Kohm
R2 = (V_en)/(I_hist + 1uA) = 26836ohm
R1 = 330Kohm R2 = 27Kohm
V_out - Set point
V_out = 3v3
V_out = V_ref*(R5/R6 - 1)
R5 = 9K1 R6 = 1K8 V_OUT = 3V24
Catch diode
Slow Start 1.32mS
Bulk Capacitors Delta V_in = 1.1V
Output Filter
L_min = (V_out * (Vin_max - Vout))/(Vin_max * K_ind * I_out * f_sw)
L_min = 6.8uH
Co_min = 1/(2*pi*F_CO(max))
Co_min = 6.875uF -> 10uF
ESR_max = 47.87mOhm

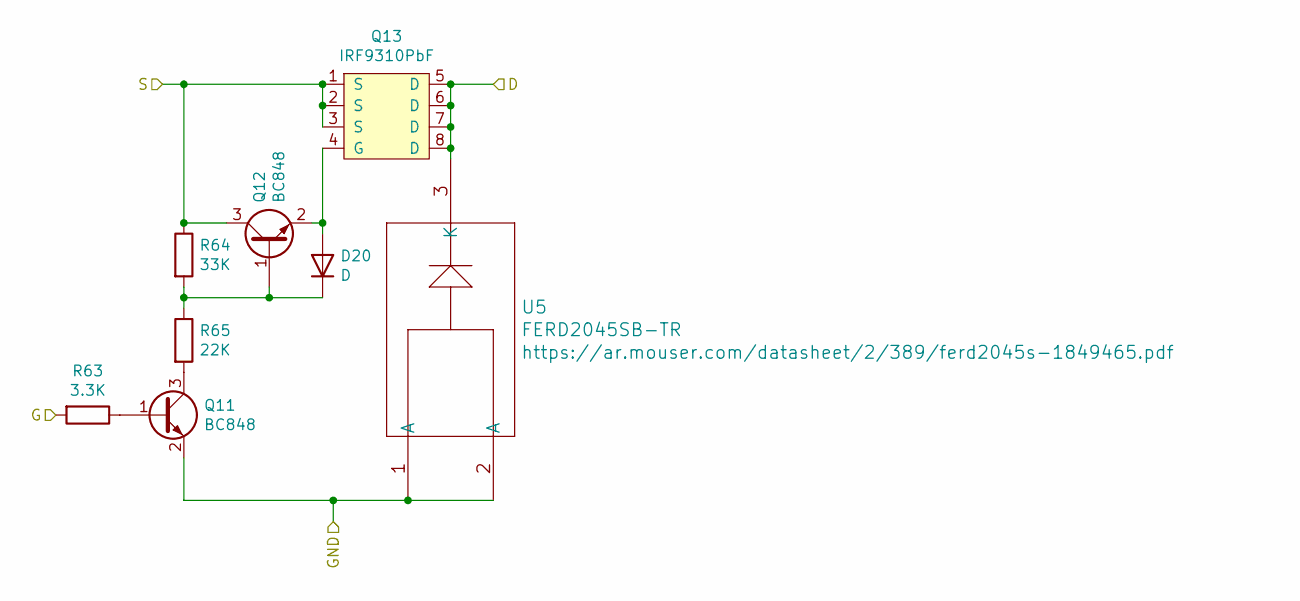
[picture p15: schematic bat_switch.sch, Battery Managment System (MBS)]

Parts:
D20: D; D_SMA
Q11, Q12: BC848; SOT-23
Q13: IRF9310PbF; SO-8_3.9x4.9mm_P1.27mm
R63: 3.3K; R_0805_2012Metric_Pad1.20x1.40mm_HandSolder
R64: 33K; R_0805_2012Metric_Pad1.20x1.40mm_HandSolder
R65: 22K; R_0805_2012Metric_Pad1.20x1.40mm_HandSolder
U5: FERD2045SB-TR; TO-252-2

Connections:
/LOAD_OUTPUT+: Q12.3 (C), Q13.1 (S), Q13.2 (S), Q13.3 (S), R64.1; also elsewhere on the board
unnamed: D20.1 (K), Q12.1 (B), R64.2, R65.1
unnamed: D20.2 (A), Q12.2 (E), Q13.4 (G)
unnamed: Q11.1 (B), R63.1
unnamed: Q11.3 (C), R65.2

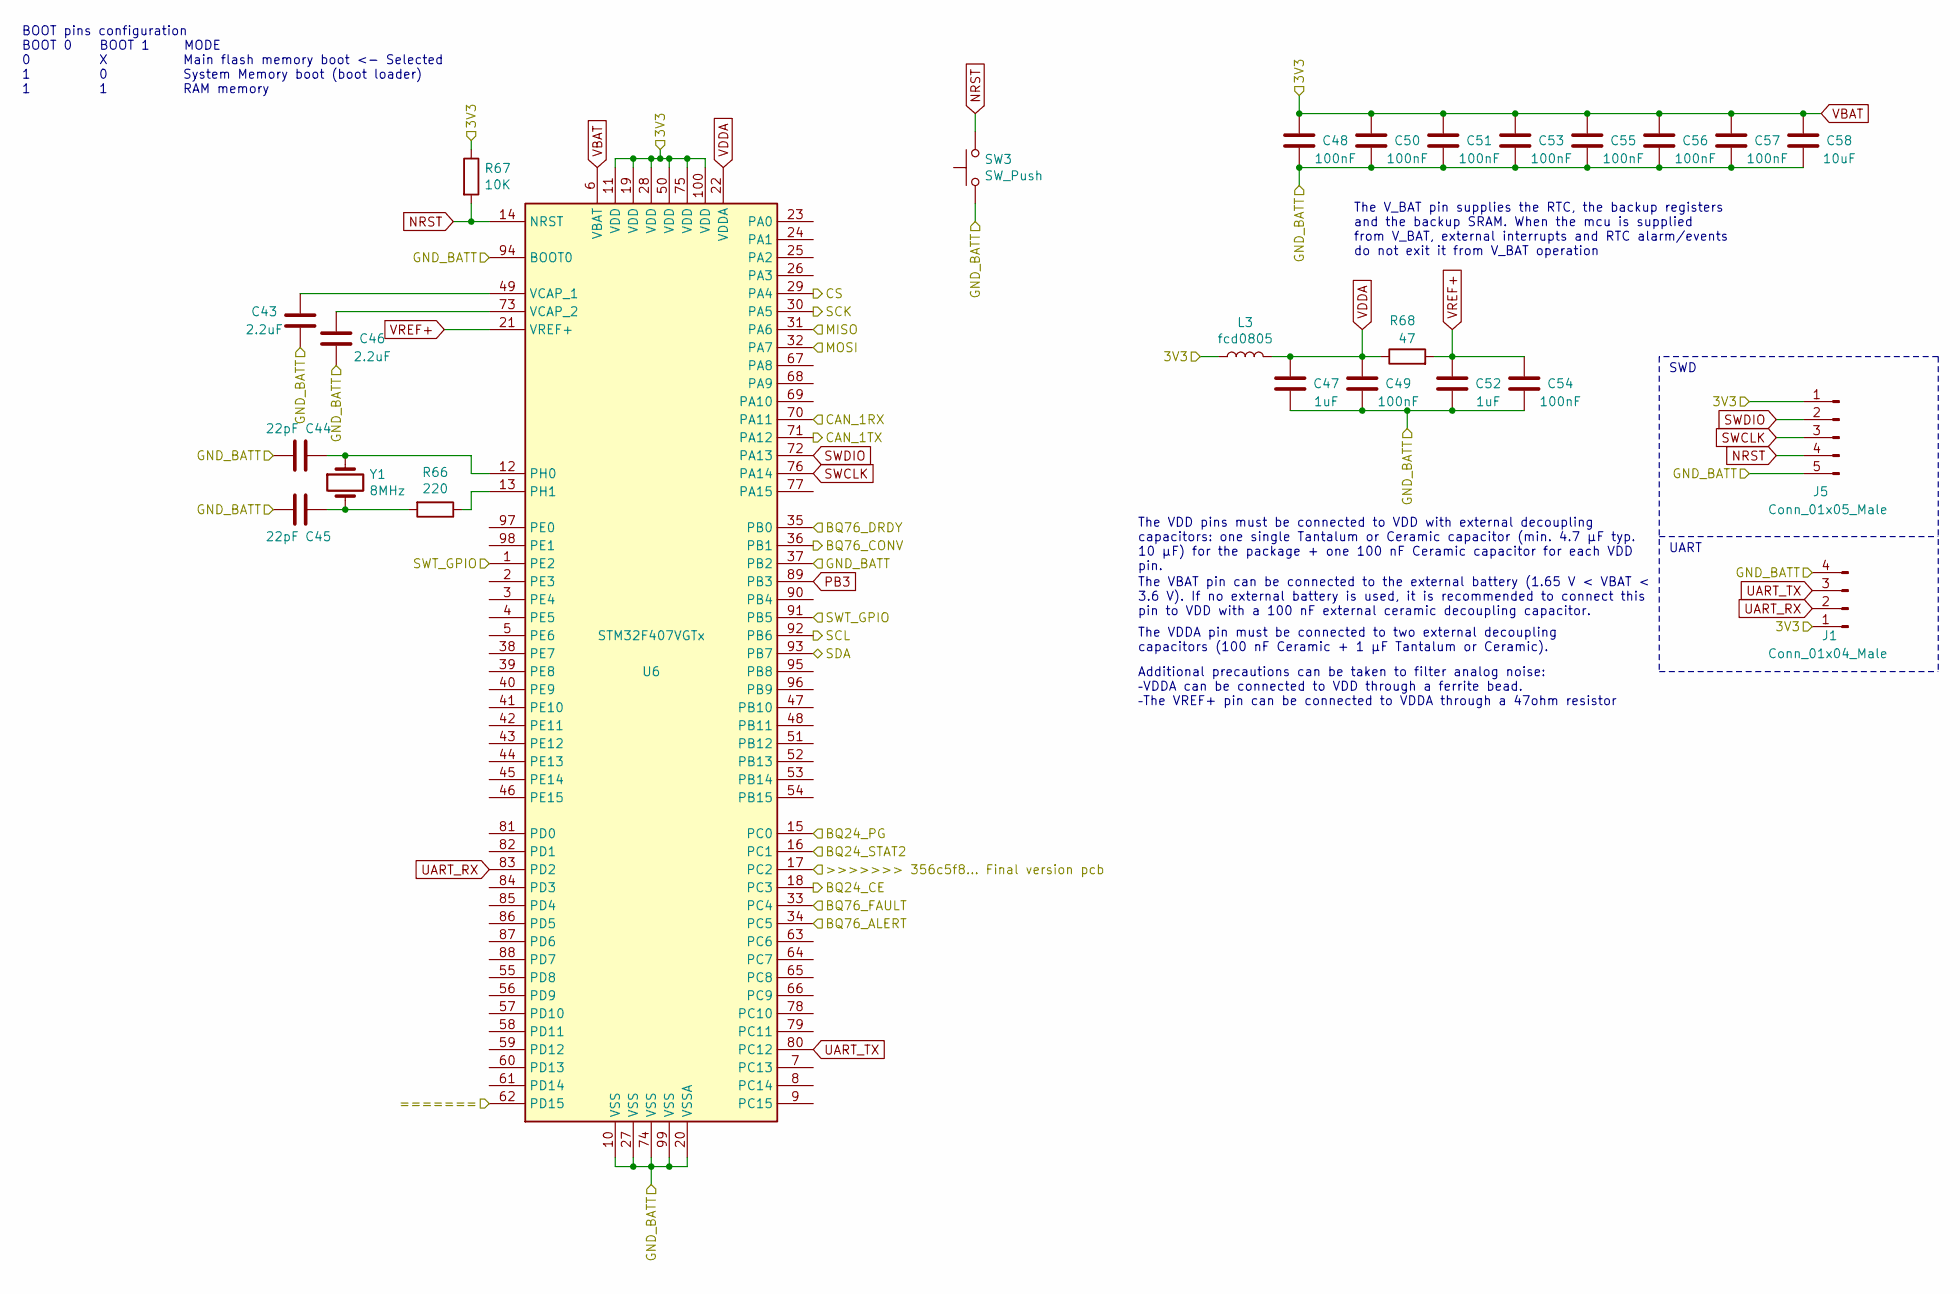
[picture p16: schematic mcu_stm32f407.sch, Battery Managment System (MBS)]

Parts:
C43, C46: 2.2uF; C_0805_2012Metric_Pad1.18x1.45mm_HandSolder
C44, C45: 22pF; C_0805_2012Metric_Pad1.18x1.45mm_HandSolder
C47, C52: 1uF; C_0805_2012Metric_Pad1.18x1.45mm_HandSolder
C48, C49, C50, C51, C53, C54, C55, C56, C57: 100nF; C_0805_2012Metric_Pad1.18x1.45mm_HandSolder
C58: 10uF; C_0805_2012Metric_Pad1.18x1.45mm_HandSolder
J1: Conn_01x04_Male; PinHeader_1x04_P2.54mm_Vertical
J5: Conn_01x05_Male; PinHeader_1x05_P2.54mm_Vertical
L3: fcd0805; L_0805_2012Metric_Pad1.05x1.20mm_HandSolder
R66: 220; R_0805_2012Metric_Pad1.20x1.40mm_HandSolder
R67: 10K; R_0805_2012Metric_Pad1.20x1.40mm_HandSolder
R68: 47; R_0805_2012Metric_Pad1.20x1.40mm_HandSolder
SW3: SW_Push; SW_PUSH_6mm_H4.3mm
U6: STM32F407VGTx; LQFP-100_14x14mm_P0.5mm
Y1: 8MHz; Crystal_SMD_HC49-SD

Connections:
/current_sensor_ina226/SCL: U6.92 (PB6); also elsewhere on the board
/current_sensor_ina226/SDA: U6.93 (PB7); also elsewhere on the board
/equalizer_bq76/ALERT_BQ76: U6.34 (PC5); also elsewhere on the board
/equalizer_bq76/CS: U6.29 (PA4); also elsewhere on the board
/mcu_stm32f407/BQ24_CE: U6.18 (PC3); also elsewhere on the board
/mcu_stm32f407/BQ24_PG: U6.15 (PC0); also elsewhere on the board
/mcu_stm32f407/BQ24_STAT1: U6.17 (PC2); also elsewhere on the board
/mcu_stm32f407/BQ24_STAT2: U6.16 (PC1); also elsewhere on the board
/mcu_stm32f407/BQ76_CONV: U6.36 (PB1); also elsewhere on the board
/mcu_stm32f407/BQ76_DRDY: U6.35 (PB0); also elsewhere on the board
/mcu_stm32f407/BQ76_FAULT: U6.33 (PC4); also elsewhere on the board
/mcu_stm32f407/CAN_1RX: U6.70 (PA11); also elsewhere on the board
/mcu_stm32f407/CAN_1TX: U6.71 (PA12); also elsewhere on the board
/mcu_stm32f407/MISO: U6.31 (PA6); also elsewhere on the board
/mcu_stm32f407/MOSI: U6.32 (PA7); also elsewhere on the board
/mcu_stm32f407/SCK: U6.30 (PA5); also elsewhere on the board
NRST: J5.4, R67.2, SW3.2, U6.14 (NRST)
unnamed: C43.1, U6.49 (VCAP_1)
unnamed: C44.2, U6.12 (PH0), Y1.1
unnamed: C45.2, R66.2, Y1.2
unnamed: C46.1, U6.73 (VCAP_2)
unnamed: R66.1, U6.13 (PH1)
PB3: U6.89 (PB3)
SWCLK: J5.3, U6.76 (PA14)
SWDIO: J5.2, U6.72 (PA13)
UART_RX: J1.2, U6.83 (PD2)
UART_TX: J1.3, U6.80 (PC12)
VBAT: C48.1, C50.1, C51.1, C53.1, C55.1, C56.1, C57.1, C58.1, J1.1, J5.1, L3.1, R67.1, U6.6 (VBAT), U6.11 (VDD), U6.19 (VDD), U6.28 (VDD), U6.50 (VDD), U6.75 (VDD), U6.100 (VDD); also elsewhere on the board
VDDA: C47.1, C49.1, L3.2, R68.1, U6.22 (VDDA)
VREF+: C52.1, C54.1, R68.2, U6.21 (VREF+)

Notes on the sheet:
The V_BAT pin supplies the RTC, the backup registers and the backup SRAM. When the mcu is supplied from V_BAT, external interrupts and RTC alarm/events do not exit it from V_BAT operation
BOOT pins configuration BOOT 0 BOOT 1 MODE 0 X Main flash memory boot <- Selected 1 0 System Memory boot (boot loader) 1 1 RAM memory
SWD
The VDD pins must be connected to VDD with external decoupling capacitors: one single Tantalum or Ceramic capacitor (min. 4.7 μF typ. 10 μF) for the package + one 100 nF Ceramic capacitor for each VDD pin.
The VBAT pin can be connected to the external battery (1.65 V < VBAT < 3.6 V). If no external battery is used, it is recommended to connect this pin to VDD with a 100 nF external ceramic decoupling capacitor.
The VDDA pin must be connected to two external decoupling capacitors (100 nF Ceramic + 1 μF Tantalum or Ceramic).
Additional precautions can be taken to filter analog noise: –VDDA can be connected to VDD through a ferrite bead. –The VREF+ pin can be connected to VDDA through a 47ohm resistor
UART

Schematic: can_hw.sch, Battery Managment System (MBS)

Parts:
C59: 330nF; C_0805_2012Metric_Pad1.18x1.45mm_HandSolder
C60: 100nF; C_0805_2012Metric_Pad1.18x1.45mm_HandSolder
C61: 4.7uF; C_0805_2012Metric_Pad1.18x1.45mm_HandSolder
C62, C63: 100pF; C_0805_2012Metric_Pad1.18x1.45mm_HandSolder
J6: DB9_Male; DSUB-9_Male_Horizontal_P2.77x2.84mm_EdgePinOffset4.94mm_Hou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
R5: 100; R_0805_2012Metric_Pad1.20x1.40mm_HandSolder
R6, R7: 60; R_0805_2012Metric_Pad1.20x1.40mm_HandSolder
U1: ADuM1201AR; SOIC-8_3.9x4.9mm_P1.27mm
U7: PDM1-S12-S3-S; CONV_PDM1-S12-S3-S; PARTREV 1.02
U8: SN65HVD233; SOIC-8_3.9x4.9mm_P1.27mm

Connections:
/can_hw/CANH: C63.1, J6.7, R7.1, U8.7 (CANH)
/can_hw/CANL: C62.1, J6.2, R6.2, U8.6 (CANL)
/mcu_stm32f407/CAN_1RX: U1.2 (VOA); also elsewhere on the board
/mcu_stm32f407/CAN_1TX: U1.3 (VIB); also elsewhere on the board
GND2: C60.2, C61.2, C62.2, C63.2, J6.3, J6.6, R5.2, U1.5 (GND2), U7.4, U8.2 (GND)
ISO_3V3: C60.1, U7.6, U8.3 (VCC)
ISO_CAN_RX: U1.7 (VIA), U8.4 (R)
ISO_CAN_TX: U1.6 (VOB), U8.1 (D)
unnamed: C61.1, R6.1, R7.2
unnamed: R5.1, U8.8 (Rs)
VBAT: C59.1, U1.1 (VDD1), U7.1; also elsewhere on the board

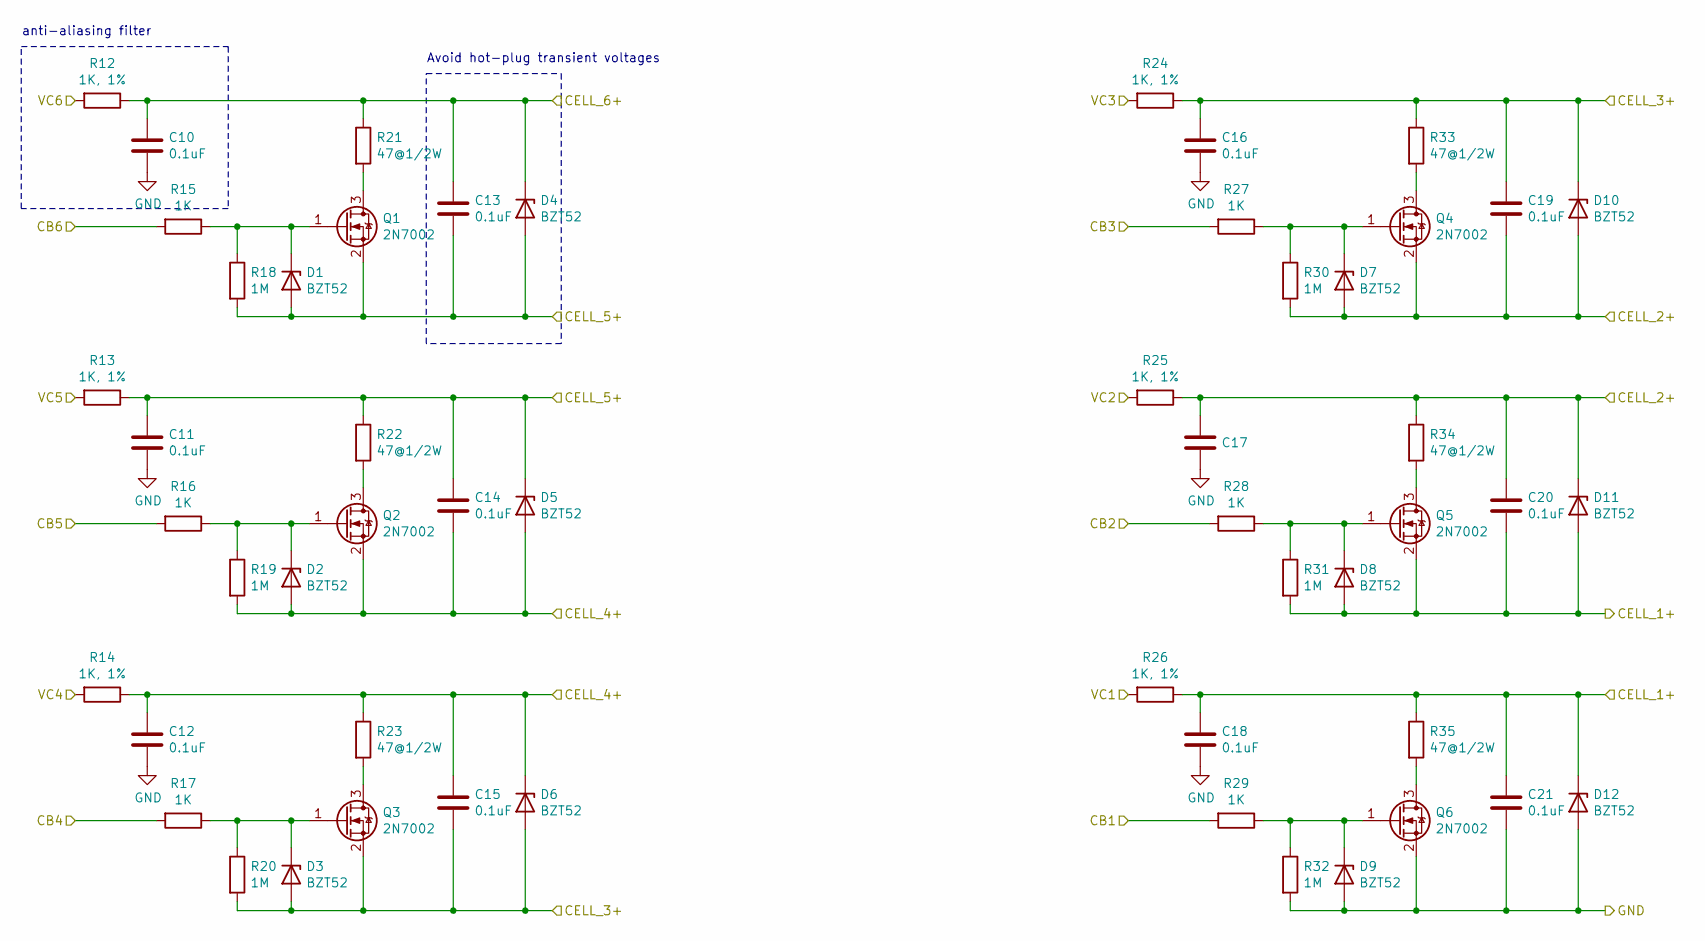
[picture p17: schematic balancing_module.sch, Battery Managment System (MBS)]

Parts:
C10, C11, C12, C13, C14, C15, C16, C17, C18, C19, C20, C21: 0.1uF; C_0805_2012Metric_Pad1.18x1.45mm_HandSolder
D1, D2, D3, D4, D5, D6, D7, D8, D9, D10, D11, D12: BZT52; D_SOD-123
Q1, Q2, Q3, Q4, Q5, Q6: 2N7002; SOT-23
R12, R13, R14, R24, R25, R26: 1K, 1%; R_0805_2012Metric_Pad1.20x1.40mm_HandSolder
R15, R16, R17, R27, R28, R29: 1K; R_0805_2012Metric_Pad1.20x1.40mm_HandSolder
R18, R19, R20, R30, R31, R32: 1M; R_0805_2012Metric_Pad1.20x1.40mm_HandSolder
R21, R22, R23, R33, R34, R35: 47@1/2W; R_1206_3216Metric_Pad1.30x1.75mm_HandSolder

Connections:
+24V: C10.1, C13.1, D4.1 (K), R12.1, R21.1; also elsewhere on the board
/equalizer_bq76/balancing_module/CB1: R29.2; also elsewhere on the board
/equalizer_bq76/balancing_module/CB2: R28.2; also elsewhere on the board
/equalizer_bq76/balancing_module/CB3: R27.2; also elsewhere on the board
/equalizer_bq76/balancing_module/CB4: R17.2; also elsewhere on the board
/equalizer_bq76/balancing_module/CB5: R16.2; also elsewhere on the board
/equalizer_bq76/balancing_module/CB6: R15.2; also elsewhere on the board
/equalizer_bq76/balancing_module/CELL_1+: C18.1, C20.2, C21.1, D8.2 (A), D11.2 (A), D12.1 (K), Q5.2 (S), R26.1, R31.2, R35.1; also elsewhere on the board
/equalizer_bq76/balancing_module/CELL_2+: C17.1, C19.2, C20.1, D7.2 (A), D10.2 (A), D11.1 (K), Q4.2 (S), R25.1, R30.2, R34.1; also elsewhere on the board
/equalizer_bq76/balancing_module/CELL_3+: C15.2, C16.1, C19.1, D3.2 (A), D6.2 (A), D10.1 (K), Q3.2 (S), R20.2, R24.1, R33.1; also elsewhere on the board
/equalizer_bq76/balancing_module/CELL_4+: C12.1, C14.2, C15.1, D2.2 (A), D5.2 (A), D6.1 (K), Q2.2 (S), R14.1, R19.2, R23.1; also elsewhere on the board
/equalizer_bq76/balancing_module/CELL_5+: C11.1, C13.2, C14.1, D1.2 (A), D4.2 (A), D5.1 (K), Q1.2 (S), R13.1, R18.2, R22.1; also elsewhere on the board
/equalizer_bq76/balancing_module/VC1: R26.2; also elsewhere on the board
/equalizer_bq76/balancing_module/VC2: R25.2; also elsewhere on the board
/equalizer_bq76/balancing_module/VC3: R24.2; also elsewhere on the board
/equalizer_bq76/balancing_module/VC4: R14.2; also elsewhere on the board
/equalizer_bq76/balancing_module/VC5: R13.2; also elsewhere on the board
/equalizer_bq76/balancing_module/VC6: R12.2; also elsewhere on the board
unnamed: D1.1 (K), Q1.1 (G), R15.1, R18.1
unnamed: D2.1 (K), Q2.1 (G), R16.1, R19.1
unnamed: D3.1 (K), Q3.1 (G), R17.1, R20.1
unnamed: D7.1 (K), Q4.1 (G), R27.1, R30.1
unnamed: D8.1 (K), Q5.1 (G), R28.1, R31.1
unnamed: D9.1 (K), Q6.1 (G), R29.1, R32.1
unnamed: Q1.3 (D), R21.2
unnamed: Q2.3 (D), R22.2
unnamed: Q3.3 (D), R23.2
unnamed: Q4.3 (D), R33.2
unnamed: Q5.3 (D), R34.2
unnamed: Q6.3 (D), R35.2

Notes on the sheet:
Avoid hot-plug transient voltages
anti-aliasing filter

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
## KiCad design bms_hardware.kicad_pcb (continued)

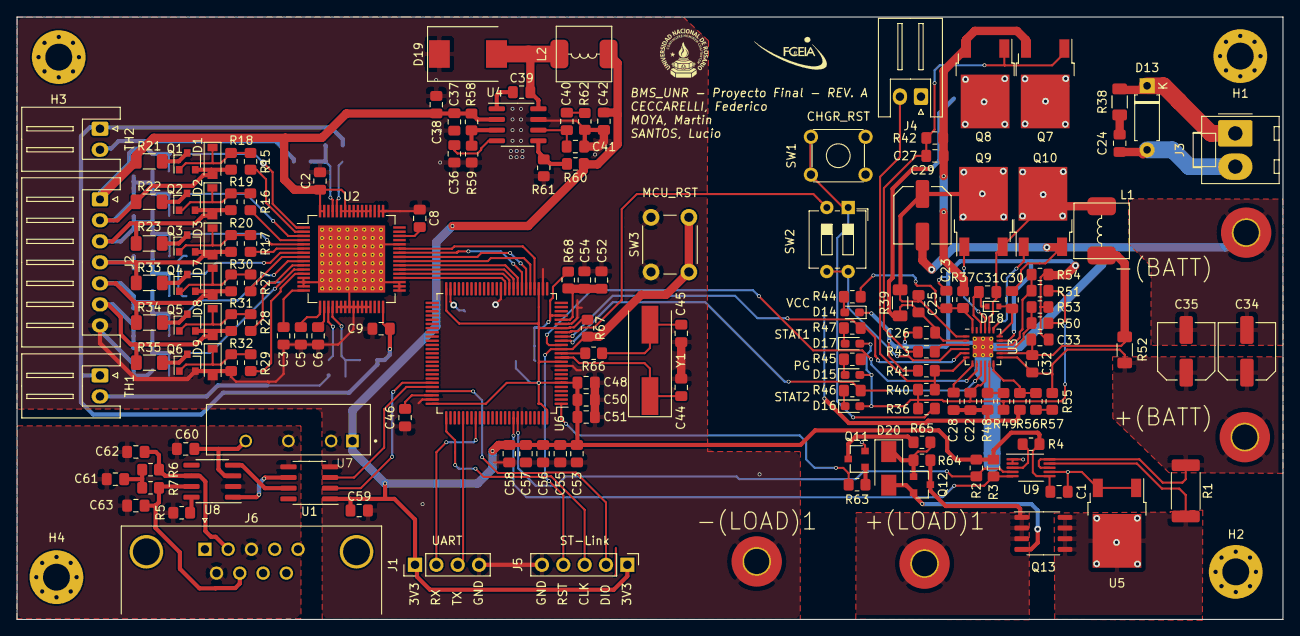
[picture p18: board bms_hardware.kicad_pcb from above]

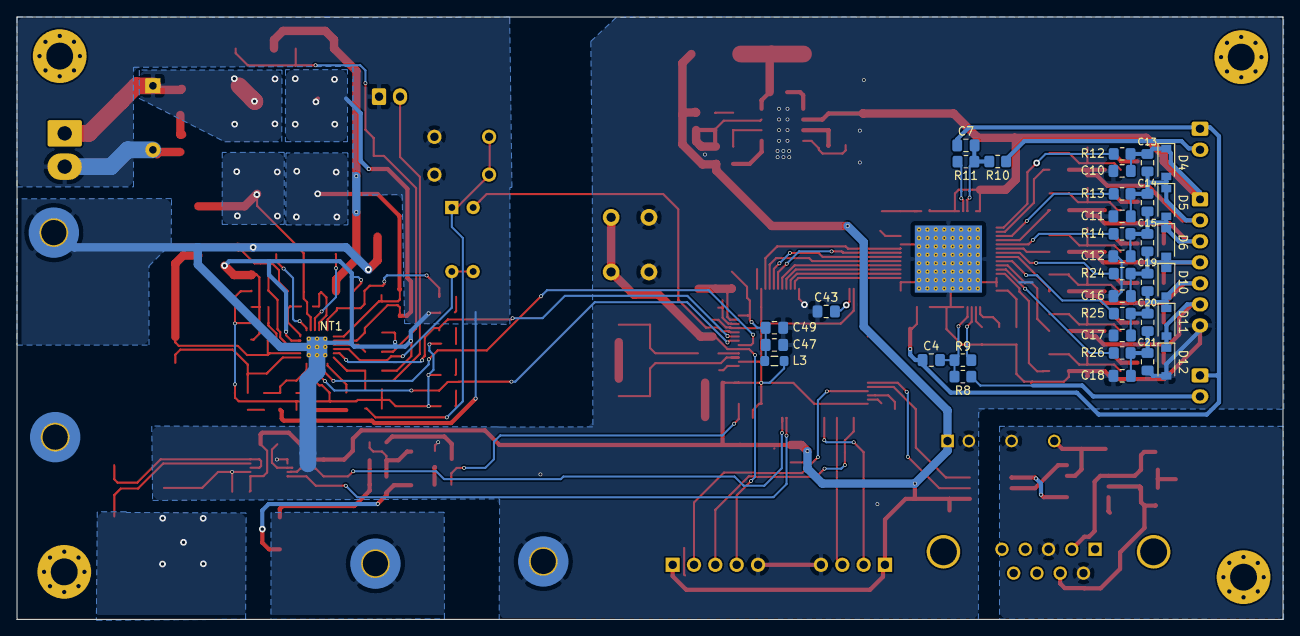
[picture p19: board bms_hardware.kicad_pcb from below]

Board: 2 copper layers, 150.6 x 71.7 mm, 197 parts (35 on the bottom side), 125 nets.

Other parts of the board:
+(BATT): MountingHole_Pad; MountingHole_3mm_Pad_TopBottom
-(BATT): MountingHole_Pad; MountingHole_3mm_Pad_TopBottom

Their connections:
+BATT: +(BATT).1; also elsewhere on the board

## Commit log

2020-03-14 Agrega .gitignore para Eagle
2020-03-14 Agrega .gitignore KiCAD por si acaso
2020-03-14 Init proyecto Kicad
    [bms_hardware.kicad_pcb, bms_hardware.sch]
2020-03-14 Agrega STM32 MCU
    [bms_hardware.sch]
2020-11-28 Agrego archivos bajados del Dropbox/Hardware/Anexos
    Creo proyecto KiCAD para crear el cargador de baterias
    [HMI.sch, Listado Componentes .xlsx, _saved_HMI.sch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]
2020-12-24 First charger sch version.
    TODO:
    + Imput Snubber
    + Select Q & N power MOS
    + Calc L & C
    + Tempr Sens
    [balancing_module.sch, bat_balancing.sch, bat_charging.sch]
2020-12-26 Adds MCU STM32F407
    [bms_hardware.kicad_pcb, bms_hardware.sch, mcu_stm32f407.sch]
2020-12-27 mmoya/bq76pl536a Adds bq76p536a
    TODO: Calculate resistance divider for temp sensors
    [balancing_module.sch, bms_hardware.sch, equalizer_bq76.sch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]
2020-12-27 mmoya/bq76pl536a Adds current sensor and IO for hierarchical sheet
    [balancing_module.sch, bms_hardware.sch, equalizer_bq76.sch]
2020-12-27 mmoya/bq76pl536a deletes unnecesary folders
    [HMI.sch, Listado Componentes .xlsx, _saved_HMI.sch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]
2020-12-27 Adds missing footprints for conns
    [balancing_module.sch, bms_hardware.sch, equalizer_bq76.sch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]
2020-12-27 Adds missing connectors footprints
    [balancing_module.sch, bms_hardware.sch, equalizer_bq76.sch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]
2020-12-27 reeplaces 0815 footprint to 0805
    [mcu_stm32f407.sch]
2020-12-28 mmoya/ina226 Adds ina226 current sensor
    - Expects a max current of 20A
    - Adds pcb footprint
    [balancing_module.sch, bms_hardware.kicad_pcb, bms_hardware.sch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]
2021-01-01 Adds SPI port to STM32F407VGxx
    [bms_hardware.sch, mcu_stm32f407.sch]
2021-01-03 Changes overlapping names of pins between bq76 and ina226
    [bms_hardware.sch, current_sensor_ina226.sch, equalizer_bq76.sch]
2021-01-14 Agrego lib de componentes faltantes al proyecto
2021-01-14 Avances del esquematico:
    + Imput Snubber DONE!
    + Select Q & N power MOS DONE!
    + Calc L & C DONE!
    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
    [bat_charging.sch]
2021-01-14 Added bat_charger.sch to main hierarchical bms project
    [balancing_module.sch, bat_charger.sch, bms_hardware.sch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]
2021-01-14 Clean old bar_charger.pro
    [bat_charging.kicad_pcb, bat_charging.sch]
2021-01-15 Charger Temperature Sensor bypassed!
    [bat_charger.sch]
2021-01-20 ADds 3v3 buck converter
    [balancing_module.sch, bat_charger.sch, bms_hardware.sch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]
2021-01-20 Reserved mcu CAN pins & edited MOS names on Bat_charger
    [bat_charger.sch, mcu_stm32f407.sch]
2021-02-06 Changes only global labels to main page
    [bat_charger.sch, bms_hardware.sch, equalizer_bq76.sch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]
2021-02-06 Adds aux pins for bq76
    [bms_hardware.sch, equalizer_bq76.sch, mcu_stm32f407.sch]
2021-02-06 Adds Can Pins
    [bat_charger.sch, bms_hardware.sch, mcu_stm32f407.sch]
2021-02-06 Add explanations of Vdd filters
    [mcu_stm32f407.sch]
2021-02-07 Dletes hw_balanceo folder
    [balancing_module.sch, bat_balancing.sch, bat_charger.sch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]
2021-02-09 se agrega switch de barteria_carga
    [Batt_2_Chrg_Switch.sch]
2021-02-09 Adds bat_switch to main sheet
    [Batt_2_Chrg_Switch.sch, balancing_module.sch, bat_charger.sch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]
2021-02-19 Fixes missing footprints, adds initial pcb
    [balancing_module.sch, bat_charger.sch, bat_switch.sch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]
2021-02-24 Added mouser reference.com to charger imput molex pin
    [bat_charger.sch, bat_switch.sch, bms_hardware.sch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]
2021-02-25 Module Can .sch and lib/PEP1-S5-D5-M added
    [Can_Hw.sch]
2021-03-09 Adds pcb file
    [bms_hardware.kicad_pcb]
2021-03-09 add minor changes to schs
    [bat_switch.sch, equalizer_bq76.sch, mcu_stm32f407.sch]
2021-03-09 Changes camel case convention to lower case
    [can_hw.sch]
2021-03-09 Adds final pcb
    [balancing_module.sch, bat_charger.sch, bat_switch.sch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]
2021-03-09 Mirrors in x axis J3
    [bat_charger.sch, bms_hardware.kicad_pcb, bms_hardware.sch]
2021-03-09 Minor fix
    [bms_hardware.kicad_pcb]
2021-03-09 Minor changes to 3v3 buck converter
    [bms_hardware.kicad_pcb]
2021-03-09 moves bom to docs folder
2021-03-09 deletes bom folder
2021-03-09 Adds rev A
    [balancing_module.sch, bat_charger.sch, bat_switch.sch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]
2021-03-09 Updates README.md, add render files
    [bms_hardware.kicad_pcb]
2021-03-09 Links BOM and render files
2021-03-09 Fixes minimum track
    [bms_hardware.kicad_pcb]
2021-03-09 Adds labels to indication leds
    [bms_hardware.kicad_pcb]
2021-03-09 Changes gnd planes clearance to 0.127mm (JLCPCB capability)
    [bms_hardware.kicad_pcb]
2021-03-09 Adds ground plane between i2c signals
    [bms_hardware.kicad_pcb]
2021-03-09 deletes unnecesary vias
    [bms_hardware.kicad_pcb]
2021-03-09 Adds gerber files
    [bms_hardware-B_Cu.gbr, bms_hardware-B_Mask.gbr, bms_hardware-B_SilkS.gbr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]
2021-03-09 Fixes silkscreen errors
    [bms_hardware-B_Cu.gbr, bms_hardware-B_Mask.gbr, bms_hardware-B_SilkS.gbr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]
2021-03-12 Edited sch page settings & printed schematic pdf
    [balancing_module.sch, bat_charger.sch, bat_switch.sch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]
2021-10-01 who knows
    [balancing_module.sch, bat_charger.sch, bat_switch.sch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]
